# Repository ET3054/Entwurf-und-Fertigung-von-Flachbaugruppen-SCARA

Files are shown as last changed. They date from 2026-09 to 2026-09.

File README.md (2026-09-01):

# # Entwurf-und-Fertigung-von-Flachbaugruppen-SCARA
 
Dieses Repository ist Teil des Modules **IE-M13-3054** der Studierenden **Dejan Dimitrijević**, **Alexander Klose** und **Jakob Cap** an der [**Hochschule für Wirtschaft und Recht (HWR) Berlin**](https://www.hwr-berlin.de/).
 
## Grundlegende Informationen
 
Dieses GitHub-Repository befasst sich mit der Entwicklung und Fertigung eines PCBs für einen SCARA-Roboter, welcher im Rahmen des Moduls **IE-M26-6045** von den Studierenden **Jakob Cap** und **David Kowalczyk** entwickelt wurde.


  
## Repository-Struktur
 
```
├── sw/
│   ├── libraries/
|       └── XX/              	 # 
│   └── Code/              		 # 
|       └── XX/       				 # 
|       └── XX/           		 # 
├── proj/
│   └── Altimate Designer/     # PCB-Projekt
├── docs/
│   └── 3D-Design/             # 3D Dateien und technische Zeichnungen
│   └── Datenblätter/          # Datenblätter der Komponenten
│   └── Pinouts/               # Pinouts der Komponenten
└── README.md
```
## Fortschritt

 - [ ] PCB Erstellen
 - [ ] 3D Modell anpassen
 - [ ] ....

## Installation

## Nutzung

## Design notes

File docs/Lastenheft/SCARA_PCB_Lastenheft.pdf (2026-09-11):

# Lastenheft: Entwurf und Optimierung einer

# Leiterplatte zur Ansteuerung eines SCARA-Roboters

### Cap, Dimitrijevic, Klose ´

### 11. September 2026

## 1 Projektubersicht ¨

Dieses Lastenheft beschreibt die Anforderungen an eine neu zu entwickelnde Leiterplatte, die die bisherige Kombination aus ESPduino32, CNC Shield V3 und vier TMC2209-Treibermodulen im bestehenden SCARA-DJ01 ersetzt. Die Platine wird als Einzelstuck f ¨ ur den Eigenbedarf des ¨ Projekts gefertigt.

## 2 Funktionale Anforderungen

- Die Platine muss einen ESP32-Mikrocontroller als zentrale Recheneinheit enthalten.
- Die Platine muss vier Steckplatze f ¨ ur die Schrittmotortreiber-Module TMC2209-V1.3 mit ¨ der passenden Pinanordnung besitzen.
- Jeder der vier Treiberplatze soll f ¨ | ur den Betrieb im UART-Single-Wire-Modus ausgelegt ¨
sein, d.h. je Treiber eine UART-Verbindung
- Die Platine muss pro Achse eine eigene STEP- und DIR-Leitung zwischen ESP32 und Treiberplatz besitzen.
- An jedem Treiberpin fur die Motorversorgung muss ein ¨ | 100 µF-Elektrolytkondensator
gegen GND verbunden werden.
- Die Platine muss einen PWM-Ausgang zur Ansteuerung eines Servomotors fur den Grei- ¨ fer haben, inklusive Spannungsversorgung fur den Servo, im Optimalfall getrennt von ¨ der Logikspannung.
- Die Platine muss eine Statusanzeige mittels einer ansteuerbaren LED bereitstellen.
- Die Platine muss neben einer externen Bluetooth-Schnittstelle einen zusatzlichen USB- ¨ Anschluss fur die Programmierung und serielles Debugging besitzen. ¨

1

- Die Platine muss eine ausreichend stabilisierte Logikversorgung (3,3 V) fur den ESP32 ¨ und die Treiber bereitstellen.
- Die Platine muss einen Reset-Taster und einen Boot-Taster fur den ESP32 bereitstellen. ¨
- Die Platine muss eine Not-Aus-Funktion haben, die die ENABLE-Leitungen aller Treiber deaktiviert.
- Die Platine muss pro Achse mindestens ein digitales Eingangssignal fur einen Endschal- ¨ ter (Homing) verarbeiten.

## 3 Nicht-funktionale Anforderungen

- Die Platine muss mit einer Eingangsspannung von 24 V DC betrieben werden konnen. ¨
- Die maximale Außenabmessung der Platine darf 100 mm x 90 mm nicht uberschreiten. ¨
- Ein Treiberausgang muss einen Strom von mindestens 1,2 A pro Achse liefern konnen, ¨
die anderen Ausgange einen Strom von ¨ | 0,6 A.
- Die Platine muss uber mindestens vier Befestigungsbohrungen verf ¨ | ugen, deren Lochbild ¨
mit der 3D-gedruckten Montagehalterung kompatibel ist.
- Die Platine muss fur PLA-vertr ¨ | agliche Betriebstemperaturen ausgelegt sein. ¨
- Die Platine muss reproduzierbar durch Standard-Leiterplattenhersteller (z.B. JLCPCB) fertigbar sein.
- Alle Anschlussklemmen fur Motor- und Versorgungsspannung m ¨ | ussen f ¨ | ur den vorge- ¨
sehenen Maximalstrom ausgelegt sein.

2

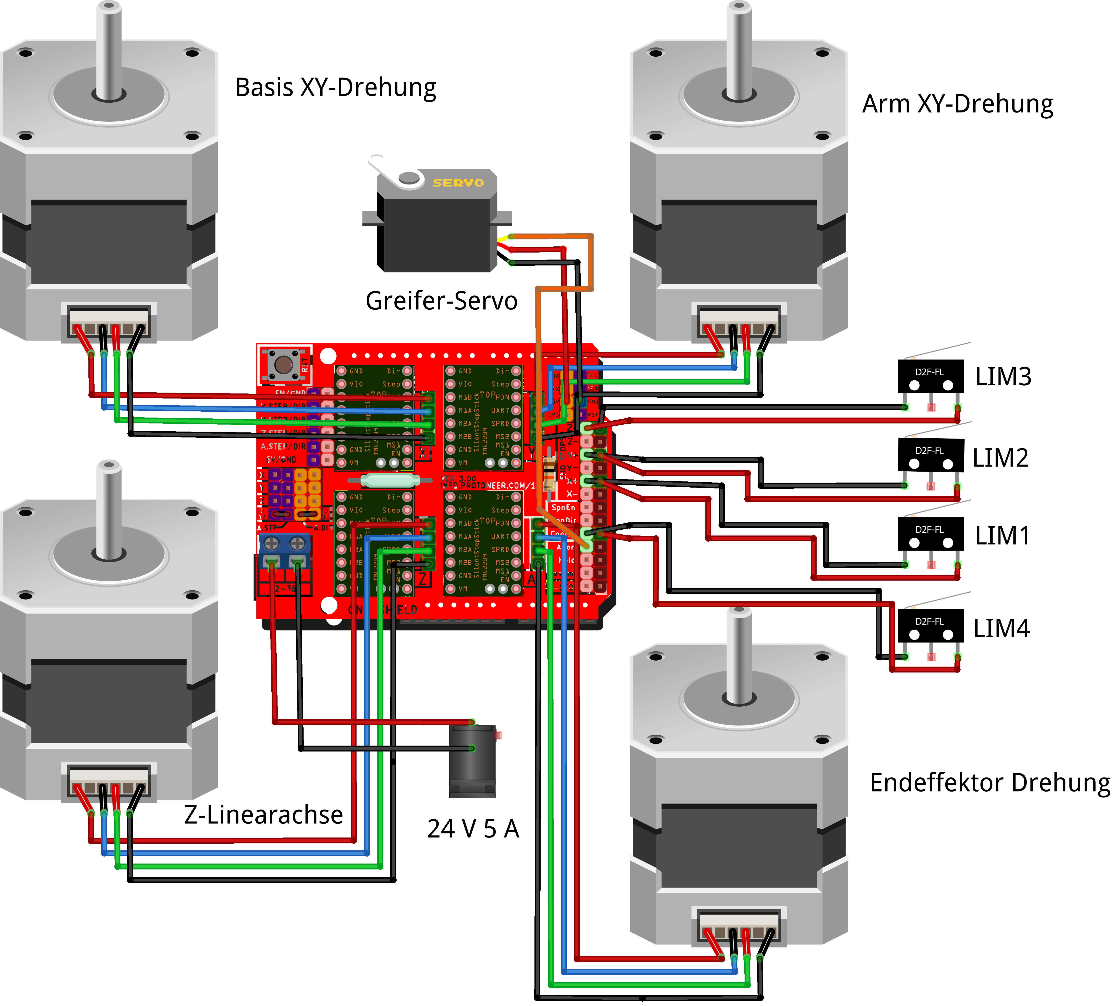
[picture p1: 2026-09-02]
docs/Schaltplan/SCARA_Symbolschaltplan_Steckplatine.png

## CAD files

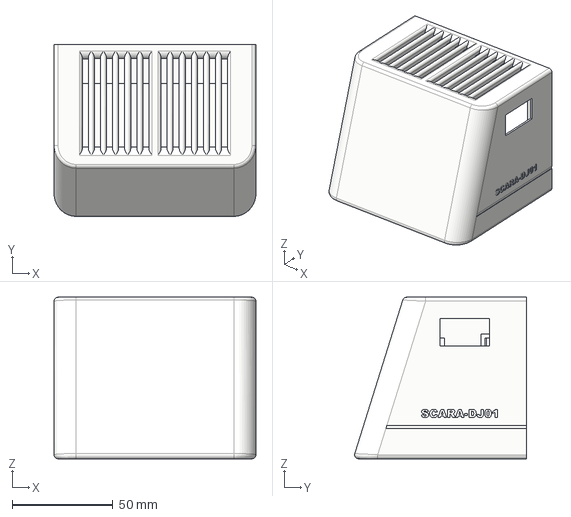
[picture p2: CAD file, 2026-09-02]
docs/3D-Design/Mikrocontrollergehäuse.step
100.0 x 85.1 x 80.0 mm

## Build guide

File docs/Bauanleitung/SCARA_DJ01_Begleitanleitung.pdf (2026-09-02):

# SCARA-Roboter

## Bauanleitung

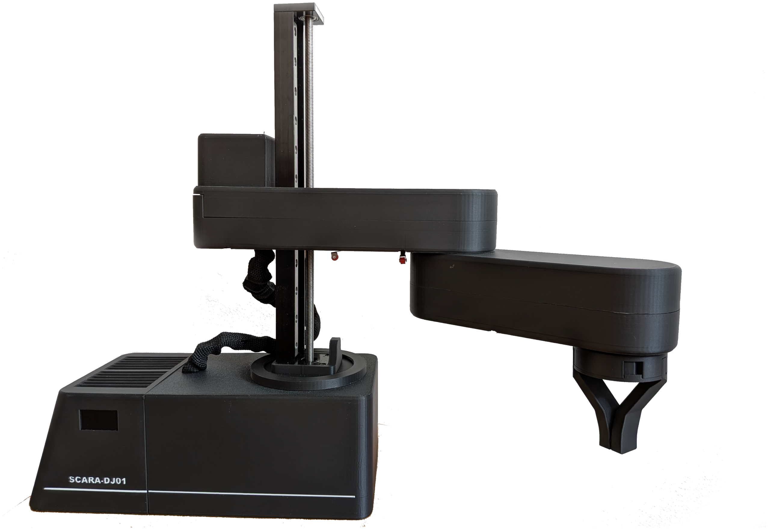
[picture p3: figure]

Datum: | 18. August 2026
Autoren: | Jakob Cap & David Kowalczyk
Fachrichtungen: | Elektrotechnik & Maschinenbau
Hochschule - Fachbereich: | HWR Berlin - Duales Studium · Technik

Einleitung

Diese Bauanleitung beschreibt den mechanischen und elektrischen Aufbau des SCARA-DJ01. Der Roboter kann einfach Handhabungsaufgaben, wie z.B. Pick-and-Place Vorgänge ausführen. Die Anleitung soll ermöglichen, den Roboter reproduzierbar aufzubauen, zu verkabeln, in Betrieb zu nehmen, zu testen und Fehler zu beheben. Dabei richtet sich die Anleitung an den Betreuer des Projekts, Studierende der industriellen Elektrotechnik und des Maschinenbaus an der HWR Berlin und Dozenten. Es werden Grundkenntnisse im sicheren Umgang mit elektrischer Spannung, mechanischer Montage, Löten und C++-Software vorausgesetzt.

Bauteilliste

Pos. | Bauteil | Bild | Anzahl | Link

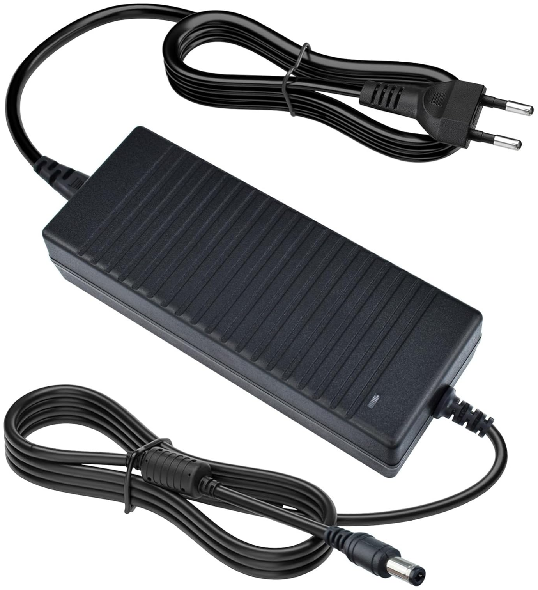
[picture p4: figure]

1 | 24 V 5 A DC-Netzteil | 1 | Amazon, (https://www.amazon.de/TOBWOLF-Netzteil-Transformatoren-Netzkabel-Sicherheitssystem-24V-5A/dp/B0BG2VMQ5Q) Aliexpress (https://de.aliexpress.com/item/4000521124523.html?curPageLogUid=9aQRAmsq0nmV)
2 | Linearmodul mit NEMA 11
Schrittmotor 6 mm Pitch
1 | Aliexpress (https://de.aliexpress.com/item/1005004275455626.html?src=google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)
3 | NEMA 11 Schrittmotor
28HS32
2 | Aliexpress, (https://de.aliexpress.com/item/4001149520746.html?curPageLogUid=TISHezQpxpRL) Reichelt (https://www.reichelt.de/de/de/shop/produkt/schrittmotor_nema_11_1_8_0_42_a_5_0_v-335321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)
4 | NEMA 17 Schrittmotor
17HS44
1 | Aliexpress, (https://de.aliexpress.com/item/1005008459399126.html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) Reichelt (https://www.reichelt.de/de/de/shop/produkt/hybridschrittmotor_nema_17_1_8_1_7_a_2_6_v-237908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)

Pos. | Bauteil | Bild | Anzahl | Link
5 | ESPduino32 | 1 | Aliexpress, (https://de.aliexpress.com/item/1005007244260396.html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) Funduino (https://funduinoshop.com/elektronische-module/wireless-iot/esp-wifi/esp32-mikrocontroller-in-uno-r3-bauform-espduino)
6 | CNC Shield V3 | 1 | Aliexpress, (https://de.aliexpress.com/item/1005006478108991.html?curPageLogUid=ZafbMuwv8aRX) Amazon (https://www.amazon.de/AZDelivery-Development-Schrittmotor-Treiber-Stepper/dp/B07CZDC9TZ)
7 | TMC2209 V1.3 Motortreiber | 4 | Aliexpress, (https://de.aliexpress.com/item/33029587820.html?curPageLogUid=3HkojVzsOqyq) Amazon (https://www.amazon.de/dp/B07WC71M4R?s=industrial&aref=RK0spETctn&sp_csd=d2lkZ2V0TmFtZT1zcF9kZXRhaWw)
8 | MG 90S Servomotor | 1 | Aliexpress, (https://de.aliexpress.com/item/1005006860780474.html?curPageLogUid=dfiFTHE6xUiC) Funduino (https://funduinoshop.com/elektronische-module/elektromotoren-und-zubehoer/elektromotoren/servomotoren/mg90s-metallgetriebe-micro-servo)
9 | Mikroendschalter mit Rollen-
kipphebel
1 | Aliexpress, (https://de.aliexpress.com/item/32949604342.html?curPageLogUid=4iSikhvUUPu3) Reichelt (https://www.reichelt.de/de/de/shop/produkt/mikroschalter_250_v_5a_1_wechsler_rollenhebel-375538)
11 | 608 Kugellager | 1 | Aliexpress, (https://de.aliexpress.com/item/1005004178119738.html?curPageLogUid=6WVQxUqaA1Xa) Amazon (https://www.amazon.de/Flewdart-Kugellager-reibungsarm-Skateboard-Abgedichtete/dp/B0FFSB9KJ4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)
12 | Nadellager mit drei Zwi-
schenlegscheiben 25x42x2
mm
1 | Aliexpress (https://de.aliexpress.com/item/1005004683503096.html)

Pos. | Bauteil | Bild | Anzahl | Link
12 | 6808 Lager 40x52x7 mm | 2 | Aliexpress, (https://de.aliexpress.com/item/32872164823.html?curPageLogUid=O13U8dG7CfZN) Amazon (https://www.amazon.de/Kugellager-40x52x7mm-Rillenkugellager-Chromstahl-Metalldichtung/dp/B0GYR3NZ1Z)
10 | GT2 Zahnriemenrad 20T-B5 | 3 | Aliexpress, (https://de.aliexpress.com/item/32995102911.html?curPageLogUid=Ju1FCh2re4OX) Amazon (https://www.amazon.de/Saipor-Zahnscheibe-Riemenscheibe-3D-Druckerteile-Zahnriemen/dp/B08X6G1WDT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)
13 | GT2 Zahnriemenspanner, mit
oder ohne Zähne, 3 mm Bohrung
4 | Aliexpress (https://de.aliexpress.com/item/1005006739452921.html?curPageLogUid=DccJLg3lUhv1) Amazon (https://www.amazon.de/Saipor-Riemenscheibe-Aluminium-Zahnriemenscheibe-Zahnriemen/dp/B092TBGXM2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)
14 | GT2-Zahnriemen
1 x 200 mm, 1 x 300 mm und 1 x 400 mm
3 | Aliexpress, (https://de.aliexpress.com/item/1005008834290222.html?curPageLogUid=SjkIp3WtWxXC) Amazon (https://www.amazon.de/Drucker-Zahnriemen-Gummiriemen-Geschlossen-3D-Drucker/dp/B0DZ6TKM8Z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)
15 | DC Power Jack | 1 | Aliexpress, (https://de.aliexpress.com/item/4001206395694.html?curPageLogUid=GMWh1VnNgcp4) Amazon (https://www.amazon.de/PATIKIL-5-5x2-5mm-Verbinder-Weiblich-Steckdose/dp/B0CLHW9CRS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)
16 | Geflochtene Kabelhülse
Innendurchmesser 10 mm
1 | Aliexpress, (https://de.aliexpress.com/item/1005007571116976.html) Amazon (https://www.amazon.de/erweiterbar-kabelschlauch-kabelstrumpf-kabelschutz-kabelmantel/dp/B071ZV6MLG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)

Pos. | Bauteil | Bild | Anzahl | Link
17 | Schrauben-Set | ∞ | Aliexpress, (https://de.aliexpress.com/i/1005007345768217.html) Amazon (https://www.amazon.de/Bnnrjia-Senkkopfschrauben-Maschinenschrauben-Flachkopfschrauben-Unterlegscheiben/dp/B0F4KJ4PNW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)

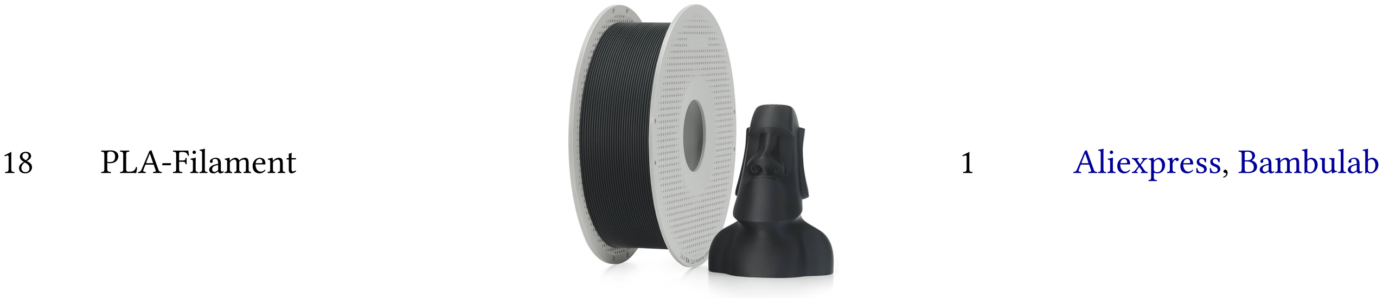
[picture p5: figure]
PLA-Filament; Aliexpress, Bambulab

19 | 0,96 Zoll OLED Display*¹
1 | Aliexpress, (https://de.aliexpress.com/item/1005007983263816.html?scm_id=1007.40050.354490.0&scm-url=1007.40050.354490.0) Amazon (https://www.reichelt.de/de/de/shop/produkt/mikroschalter_250_v_5a_1_wechsler_rollenhebel-375538)
20 | Dupont Stecker-Set*²
1 | Aliexpress, (https://de.aliexpress.com/item/1005011870146881.html?scm_id=1007.40050.354490.0&scm-url=1007.40050.354490.0) Amazon (https://www.amazon.de/Crimpzange-Dupont-Stecker-Steckverbinder-Crimpkontakten/dp/B07QX51F3B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)
21 | Schrumpfschläuche verschie-
dener Größen*²
∞ | Aliexpress, (https://de.aliexpress.com/item/1005011989139972.html?curPageLogUid=mRC6HR2zQCps) Amazon (https://www.amazon.de/sourcing-map-Schrumpfschlauch-Verh%C3%A4ltnis-Schrumpfschl%C3%A4uche/dp/B01LFJCOJ4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)
22 | Einschmelzgewinde M3 x 4
mm
4 | Aliexpress, (https://de.aliexpress.com/item/1005006472962973.html?curPageLogUid=pWqwgmMtMx5g) Amazon (https://www.amazon.de/Eins%C3%A4tze-Befestigung-metrische-Schraube-Kunststoff/dp/B09NWH5T9Kalie)

1
optional
2
hilfreich, wenn nicht vorhanden

Benötigte Werkzeuge

{ Benötigte Teile und Werkzeuge

- Schraubendreher,
- Inbusschlüssel,
- Seitenschneider/Cuttermesser,
- Multimeter,
- Lötkolben und Lötzinn,
- USB-B-Kabel,
- Laptop mit Entwicklungsumgebung und Slicing-Software,
- 3D-Drucker,
- Abisolierzange*³
,
- Crimpzange*³

Fertigung der 3D-Druck-Komponenten

1. Benötigte Ausrüstung und Material:
- Beliebiger 3D-Drucker (z.B. Bambulab P1S) mit 0,4 mm Düse
- Filament: PLA (Polylactide), Farbe optional
- Slicing-Software zum Erstellen des G-Codes für den 3D-Drucker
- Nachbearbeitung: Seitenschneider, Entgrater für das Entfernen von Stützstrukturen und Rückständen beim Drucken
2. Vorbereitung für den Druck:
- Laden der „SCARA-DJ01 3D Druck Komponenten“ in die Slicing-Software (z.B. Bambu Studio)
- Druckeinstellungen gemäß der unten abgebildeten Tabelle einstellen
- Druckvorschau überprüfen, ob Stützstrukturen, Druckzeit und Materialverbrauch stimmen
- Reinigen der Druckplatte
- Funktion „Outer brim“ im Slicer aktivieren für bessere Druckbetthaftung bei großen Bauteilen
- Druck starten

3
nicht zwingend notwendig

3. Druckeinstellungen:
Parameter | Wert
Fertigungsverfahren | FDM
Drucker | Bambulab P1S
Material | Polylactide PLA
Düsendurchmesser | 0,4 mm
Schichthöhe | 0,12 mm Fine
Fülldichte (Infill) | 15%
Stützstrukturen | tree oder normal
Druckorientierung | funktionsabhängig
4. Prüfen und Nachbearbeiten:
- Bauteile auf Maßhaltigkeit prüfen
- Probleme beim Druck? Evtl. schlechte Druckbetthaftung, wodurch es zum Verzug der Bauteile kam?
- Stützstrukturen an Bauteilen vorsichtig entfernen, insbesondere bei Kabelführungen, Passungen und Funktionsflächen achtgeben
- Bei optionaler Einstellung „Outer brim“ Rand nach der Fertigstellung zur Sicherheit entfernen
- Beim Installieren von Kugellagern in den 3D-gedruckten Bauteilen auf Sauberkeit der Passflächen achten

Montage und Inbetriebnahme des Roboters

Schritt 1

Nach Fertigstellung der 3D-gedruckten Bauteile wird das Mikrocontroller-Gehäuse zur Hand genommen und es werden die Messing-Einschmelzgewinde eingesetzt. Dafür sind vier Löcher an der Rückwand des Mikrocontroller-Gehäuses vorgesehen. Mithilfe z.B. eines heißen Lötkolbens werden die M3 x 4 mm-Gewinde vorsichtig in den Kunststoff eingeschmolzen.

ò

Falls das optionale OLED-Display verbaut werden soll, ist es ratsam, kurz zum sechsten Schritt in dieser Anleitung zu springen und anschließend mit Schritt 2 fortzufahren.

Schritt 2

Im zweiten Schritt wird der ESPduino32 an die entsprechenden Löcher gesetzt und mit vier M3 x 6-Schrauben gesichert. Die Schrauben sollten leicht handfest angezogen werden. Es ist darauf zu achten, dass die Aussparungen am Mikrocontrollergehäuse und die Anschlüsse des ESPduino32 korrekt ausgerichtet sind.

Da der ESP in dieser Position am leichtesten erreichbar ist und beim späteren Hochladen des Codes Probleme auftreten könnten, wird die Software bereits jetzt auf den Mikrocontroller übertragen. Damit das Programm SCARA_DJ01_control_sw auf den ESPduino übertragen werden kann, muss der Mikrocontroller in den Bootloader-Modus versetzt werden. Beim Einschalten prüft der ESP den Zustand bestimmter Pins. Ist der Pin GPIO0 mit GND verbunden, startet er nicht das bereits gespeicherte Programm, sondern wechselt in den Bootloader-Modus und wartet auf das Aufspielen einer Software. Bei Verwendung eines geeigneten USB-Kabels und den entsprechenden Einstellungen in der Arduino IDE sorgt eine Schaltung auf der Leiterplatte dafür, dass der Bootloader-Modus automatisch aktiviert werden kann. Sollte dies nicht funktionieren und beim Flashen wird eine Fehlermeldung ausgegeben, muss der Pin GPIO0 manuell mit GND verbunden werden. Hierzu wird der Pin GPIO0 mit einem GND-Pin über ein Jumperkabel verbunden. Dann kann der Upload in der Arduino IDE gestartet werden. Nach erfolgreichem Flashen wird die Verbindung entfernt und die RESET-Taste kurz betätigt, sodass der Mikrocontroller neu startet und das aufgespielte Programm ausführt.

Optimale Einstellungen der Arduino IDE für das Flashen auf den ESPDuino

Einstellung | Wert
Board | ESP32 Dev Module
Flash Frequency | 40 MHz
Flash Mode | DIO

Erase All Flash Before Sketch Upload Enabled

Upload Speed | 115200

Schritt 3

Bevor das CNC Shield inklusive der Motortreiber auf dem ESPduino32 aufgesetzt werden, müssen die Motortreiber korrekt eingestellt werden. Die vier Schrittmotoren des SCARA-Roboters werden über je einen TMC2209 V1.3 Schrittmotortreiber angesteuert. Jeder Schrittmotor besitzt einen maximal zulässigen Phasenstrom IN, der dem Datenblatt zu entnehmen ist. Um eine thermische Überlastung des Motors zu vermeiden, muss die Referenzspannung Uref, die den Phasenstrom begrenzt, für jeden Treiber korrekt eingestellt werden.

Für die TMC2209 V1.3 Module mit einem Shunt-Widerstand von RSENSE = 0,11 Ω gilt näherungsweise folgende Gleichung:

Uref =

√
2 · IRMS

Dabei ist IRMS der gewünschte Effektivstrom des Motors, der für diesen Entwurf testweise ermittelt wurde. Für den NEMA 17-Motor mit einem angestrebten Phasenstrom von 1,2 A in diesem Entwurf
ergibt sich Uref zu | 1,7 V | .

Für die drei NEMA 11-Motoren mit einem angestrebten Phasenstrom von 0,6 A ergibt sich Uref zu 0,85 V .

ò

Da verschiedene Hersteller der TMC2209 V1.3 Module unterschiedliche Shunt-Widerstände verbauen können, ist die im Datenblatt des jeweiligen Moduls angegebene Formel stets zu überprüfen. Die in diesem Kapitel verwendeten Werte gelten ausschließlich für die im Projekt eingesetzten Treibermodule.

Uref wird über ein Potentiometer auf dem Modul eingestellt. Um die Referenzspannung mit einem Multimeter zwischen Schleifer des Potentiometers und GND-Pin zu messen, muss der Treiber mit Motorspannung versorgt sein. Dazu bietet es sich an, die Motortreiber direkt auf dem CNC Shield aufgesteckt einzustellen. Das CNC Shield muss mit Motorspannung versorgt werden, z.B. über das 24 V DC-Netzteil. Da im vierten Schritt auch der DC Power Jack benötigt wird kann dieser im Optimalfall gleich dafür verwendet werden. Der positive und negative Anschluss sollten dafür mit einem kurzen Kabel verlötet und abisoliert werden. Die offenen Enden sind den richtigen Schraubklemmen des CNC Shields zu befestigen (Unbedingt auf richtige Polarität achten!).

Folgende wichtige Hinweise bevor mit der Einstellung des Phasenstroms begonnen wird:

- Bei der Montage der Treiber auf dem CNC Shield ist unbedingt die physische Orientierung zu beachten. Andernfalls können die Treiber dadurch beschädigt werden, dass die Motorspannung auf den Logikpins anliegt.
- Der TMC2209 V1.3 ist ursprünglich nicht für die Montage auf dem CNC Shield V3 ausgelegt. Wichtig zu wissen ist, dass folglich nicht alle Pin-Belegungen beider Bauteile übereinstimmen. Trotzdem ist die Nutzung der Module möglich, es gilt nur zu beachten, dass die oberen UART-Pins (DIAG,INDEX, falls vorhanden) Kontakt mit den Kondensatoranschlüssen auf dem CNC Shield haben könnten. Das sollte vermieden werden, indem die Pins vorsichtig nach außen gebogen oder heraus gelötet werden.
- Es ist auch zu bedenken, dass die Schrittmotor-Phasenkabel nicht unter Spannung anoder abgesteckt werden sollten. Das kann zu induktiven Spannungsspitzen führen, die die Treiber ebenso beschädigen können.

Vorgehensweise zur Einstellung des Phasenstroms

Für die Einstellung werden ein Multimeter, ein Kreuz-Schlitz-Schraubendreher und eine Spannungsversorgung benötigt. Der Schrittmotor kann während der Einstellung abgesteckt bleiben. Die Einstellung erfolgt für jeden der vier TMC2209-Treiber identisch.

1. Treibermodul auf CNC Shield stecken
2. Spannungsversorgung einschalten
3. Multimeter auf Gleichspannungsmessung einstellen
4. Schwarze Messspitze mit einem GND-Pin des Treibers verbinden
5. Rote Messspitze auf das Potentiometer halten
6. Aktuelle Referenzspannung ablesen
7. Potentiometer vorsichtig drehen:

- im Uhrzeigersinn: erhöht die Referenzspannung und den Phasenstrom
- gegen den Uhrzeigersinn: verringert die Referenzspannung und den Phasenstrom
8. Einstellwert mit Sollwert vergleichen
9. Vorgang für alle restlichen Treiber wiederholen

Sind alle Treiber eingestellt können sie auf die vier Slots des CNC Shields verteilt werden. Der Treiber für den NEMA 17-Schrittmotor mit einer eingestellten Referenzspannung von 1, 7 V ist für den X-Slot vorgesehen. Die restlichen Treiber können auf die Slots Y, Z und A verteilt werden. Zur Aktivierung des A-Slots müssen Jumper auf die Male-Pin-Header D12/A.STEP und D13/A.DIR gesetzt werden (direkt über den Schraubklemmen des Shields). Schließlich kann das Shield auf den ESPduino32 aufgesteckt werden.

ò

Das CNC Shield V3 wurde ursprünglich für einen Arduino UNO R3 entwickelt. Der ESPduino32 ist ein ESP32-Mikrocontroller mit einer ähnlichen Bauform und Pin-Anordnung wie der UNO R3. Es ist festzustellen, dass manche Komponenten auf den Modulen z.B. durch Montagetoleranzen verschoben angeordnet sind. So kommt es bei manchen Modellen vor, dass der USB-B-Anschluss ein Stück weiter hinten auf dem Modul versetzt ist. Dadurch kann das Shield nicht korrekt aufgesetzt werden, da die Pins mit der Unterseite auf dem USB-Port aufliegen. Das führt wiederum dazu, dass die betroffenen Schritt- und Richtungs-Pins auf dem Erd-Potential der Schnittstelle liegen. Dadurch kam es in diesem Entwurf oft zu Ausfällen einzelner Motoren. Hier kann mit einem Seitenschneider und ein wenig Isolierband Abhilfe geschaffen werden. Wenn die betroffenen Pin-Enden auf der Unterseite vorsichtig abgeschnitten und mit Isolierband abgeklebt werden, können zukünftige Ausfälle verhindert werden.

Schritt 4

Im vierten Schritt wird der DC Power Jack mit den bereits angelöteten Kabeln in die dafür vorgesehene Aussparung im Mikrocontrollergehäuse gesteckt. Die offenen Enden werden (falls noch nicht geschehen) an den Schraubklemmen des CNC Shields befestigt. Da der Bauraum begrenzt ist, sollte die benötigte Kabellänge vom DC Power Jack zum Shield durch Ausprobieren ermittelt werden.

Schritt 5

Nun kann der 3D-gedruckte Haltebügel für den DC-Jack montiert werden. Die M2 x 6-Schrauben werden durch die vorgesehenen Löcher im Haltebügel gesteckt und dieser anschließend an die vorgesehenen Löcher im Mikrocontrollergehäuse geschraubt.

Schritt 6

Das Mikrocontrollergehäuse ist nun fertig zusammengebaut.

Falls das optionale OLED-Display montiert werden soll, ist ein wenig handwerkliches Geschick notwendig. Das Display wird in die dafür vorgesehene Passung am Gehäuse eingesetzt und mit einem langen schmalen Schraubenzieher durch die Löcher der DC-Anschlüsse im Gehäuse auf der anderen Seite festgeschraubt. Die beschrifteten I²C-Pins des Shields stimmen nicht mit den Pins auf dem ESPduino32 überein, da es ursprünglich für den UNO R3 konzipiert wurde. Die Montage ist jedoch möglich, da das CNC Shield die Pins auf dem ESPduino nicht nutzt und sie daher quasi frei sind. Man kann zwei Arduino Jumperkabel so umbiegen, dass sie im 90°-Winkel aus den freien Female-Header-Pin (SCL, SDA) des ESPduinos unter dem CNC Shield entlang geführt werden. Vcc des OLED-Displays kann mit 3, 3 V auf dem CNC Shield verkabelt werden und GND mit einem jeweiligen GND-Pin.

Schritt 7

Im siebten Schritt wird der untere Teil des großen Basis-Gehäuses verwendet. Die Welle des NEMA 17-Schrittmotors wird mit einem GT2 Antriebsrad mit 20 Zähnen bestückt und anschließend werden die Madenschrauben des Antriebsrades so angezogen, dass die Oberkante des Antriebsrads mit der Oberkante der Motorwelle abschließt. Nun kann der NEMA 17 in die dafür vorgesehene Passung im Gehäuse eingesetzt, aber noch nicht verschraubt werden. Die Kabelanschlüsse des Motors zeigen dabei in Richtung Mikrocontrollergehäuse.

Schritt 8

Das Kugellager 608 wird in die kreisrunde Passung am Boden des Gehäuses eingesetzt. Hierbei ist auf die Presspassung zu achten.

Der Lagerbolzen wird mit der kurzen Seite nach unten vorsichtig eingedrückt. Im Anschluss daran wird der NEMA 17-Motor kurz in der Passung angehoben, sodass der 200 mm GT2 Riemen um das Antriebsrad geführt werden kann. Schließlich kann auch der Motor von der Unterseite des Gehäuses mit vier M3 x 16-Schrauben befestigt werden

Schritt 9

Das GT2 Zahnriemenrad mit 60 Zähnen und einer 8 mm Bohrung wird auf den Lagerbolzen gesetzt. Dabei sollte der Riemen bereits um das Antriebs- und Abtriebsrad gelegt sein. Einer der Endlagentaster wird in die Gehäusepassung eingesetzt (Orientierung beachten). Die Kabelanschlüsse des Endlagentasters sind nach Möglichkeit zu Löten. Alle Endlagentaster sind in diesem Entwurf als Normally Closed konfiguriert. Das bedeutet der mittlere Anschluss der Taster bleibt unbelegt und nur die beiden äußeren werden verlötet. Hierfür sollten zwei ca. 20 cm lange Kabel verwendet werden, die zum Schluss des Zusammenbaus auf die richtige Länge gekürzt werden. Die gelöteten Kabelanschlüsse am Taster sind nach Möglichkeit mit etwas Isolierband oder Schrumpfschlauch zu isolieren. Die entgegengesetzten Enden der beiden Kabel können nach dem Kürzen z.B. in einen zweipoligen Dupont-Female-Connector geführt werden, sodass zum Schluss eine einfache Steckbarkeit auf dem CNC Shield gewährleistet wird.

Schritt 10

Im zehnten Schritt wird das Verbindungselement auf das Abtriebsrad gesetzt und anschließend mit einer Madenschraube gesichert. Der Endlagentaster wird mit zwei M2, 5 x 10-Schrauben in der

Passung befestigt. Da diese Schrauben direkt in das PLA gedreht werden, sollten sie nur leicht festgezogen werden. Gleiches gilt für alle folgenden Schraubverbindungen im PLA.

Schritt 11

Um den Riemen zu spannen, wird ein Riemenspanner eingesetzt. Hierzu wird die M2 x 20-Schraube von der Unterseite des Gehäuses ein kleines Stück in das Gehäuse eingeschraubt und schließlich werden zwei M2-Muttern aufgeschraubt. Danach wird der Riemenspanner aufgesetzt, sodass er den Riemen nach innen drückt. Die Schraube wird nun weiter durchgeschraubt und oben mit einer weiteren M2-Mutter gekontert und dann in das Loch an der Unterseite des NEMA 17-Halters geschraubt. Die Muttern sollten so festgeschraubt werden, dass sich der Riemenspanner leichtgängig drehen lässt.

Schritt 12

Mit dem zwölften Schritt ist die Montage des unteren Basis-Gehäuses abgeschlossen.

Schritt 13

Nun wird das Linearmodul für die Montage vorbereitet. Dazu ist ein Inbusschlüssel der Größe 2 mm notwendig. Mit diesem werden zunächst die vier Schrauben gelöst, die den Schrittmotor sichern. Anschließend wird der Schrittmotor inklusive Kugelumlaufspindel vorsichtig ein Stück aus der Schiene herausgezogen. Daraufhin wird der Motor durch das Trägerbauteil geführt und die Schiene in die Passung eingesetzt. Danach kann der Motor wieder mit der Schiene verschraubt werden.

Bei dem Aufsetzen des Kugellagers auf das Trägerbauteil ist unbedingt auf die Presspassung zu achten. Falls der Vorgang schwergängig ist, kann das Kugellager auch erst in die obere Gehäusehälfte eingepresst werden. Auf keinen Fall sollte sich auf der Oberseite des Linearmoduls abgestützt werden. Dadurch kann sich das Material verformen und die Leichtgängigkeit des Schiebers wird beeinflusst. Sollte der Schieber sich trotzdem immer noch sehr schwergängig von Hand bewegen lassen, besteht die Möglichkeit, die zwei Inbusschrauben an der Oberseite des Schiebers zu lösen und das Spiel zwischen Schieber und Schiene zu korrigieren.

Schließlich wird der Sicherungsriegel von der Oberseite über das Linearmodul geführt, sodass er mit den acht Löchern nach unten zeigend auf dem Trägerbauteil aufliegt.

Schritt 14

In diesem Schritt wird das Linearmodul durch das Loch in der oberen Basis-Gehäusehälfte geführt und das Kugellager vorsichtig in die Passung eingepresst (ggf. Kugellager zuerst einsetzen, siehe Schritt zuvor). Von der Unterseite ist der Sicherheitsriegel mit acht M3 x 8 Schrauben zu sichern.

Schritt 15

Für die Montage des ersten Roboterarms wird zuerst das Kugellager in die dafür vorgesehen Passung eingepresst. Das GT2 Abtriebsrad mit der großen Bohrung wird in den Kugellagerinnenring eingepresst. Außerdem werden zwei Endschalter für die Z-Achse und die XY-Drehung des zweiten Arms in die Passung nach der Verkabelung eingesetzt. Die Verkabelung sollte wie in Schritt 9 ausgeführt werden. Auch auf passende Kabellängen sollte geachtet werden, die dann durch die Kabelführungen in der Seitenwand des Gehäuses nach unten durch das Loch geführt werden. Da die Schalter möglicherweise in ihrer Passung verrutschen könnten, empfiehlt es sich sie durch die Löcher mit zusätzlichen Schrauben zu sichern und diese auf der anderen Seite mit einer Mutter zu kontern.

Schritt 16

Im Folgenden kann der vorbereitete Arm über das Linearmodul geführt werden und am Schieber mit vier M3 x 10 Schrauben montiert werden.

Schritt 17

Im Schritt 17 wird der obere Teil des ersten Roboterarms vorbereitet. Ein GT2 Antriebsrad mit 20 Zähnen wird auf der Motorwelle des NEMA 11-Schrittmotors befestigt. Dann wird der Motor in die Passung eingesetzt und mit vier M2, 5 x 12 Schrauben fixiert. Die vier Motorphasen-Kabel werden durch das Loch daneben nach unten geführt.

Schritt 18

Das Gehäuse für den Motor wird ebenso mit vier M2, 5 x 12 Schrauben von der Unterseite gesichert. Die Riemenspanner werden in den Aussparungen verbaut. Dafür werden zwei M2 x 20 Schrauben von oben durch das Loch gesteckt, anschließend mit einer Mutter gekontert und der jeweilige Riemenspanner wird aufgesteckt, der wiederum mit einer Mutter gekontert wird. Der 400 mm Riemen kann schon mal provisorisch außen um das Antriebsrad und die beiden Riemenspanner herumgelegt werden.

Schritt 19

Bevor die beiden Gehäuse des ersten Arms miteinander verbunden werden können, wird die obere Hälfte des zweiten Roboterarms mit der unteren Hälfte des ersten verschraubt. Dafür wird das obere Gehäuse von Arm 2 in die Passung am Arm 1 eingesetzt, sodass die Löcher auf der kreisförmigen Fläche mit den Löchern im Abtriebsrad des ersten Arms übereinstimmen. Zwei Schrauben M3 x 16 fixieren diese Verbindung und der zweite Arm sollte sich nun leichtgängig im Kugellager drehen lassen.

Schritt 20

In diesem Schritt wird der untere Teil des zweiten Arms inklusive der gesamten Verkabelung vorbereitet. Der Endschalter für die Greiferrotation wird wie in Schritt 9 vorbereitet und die Kabel werden durch die große Bohrung im Zahnriemenrad des ersten Arms, durch die Kabelführungen und durch das Loch im Boden des Gehäuses gezogen. Das letzte GT2-Antriebsrad mit 20 Zähnen wird auf der Motorwelle des NEMA 11 montiert, sodass das Antriebsrad so nah wie möglich am Motor befestigt wird, ohne zu schleifen. Bevor der Motor mit vier M2, 5 x 6 Schrauben gesichert wird, sollte der Riemen um das Antriebsrad gelegt werden. Der Motor wird so montiert, dass die Phasenkabel bei nach vorne ausgestreckten Armen in Richtung des ersten Roboterarms zeigen und die Kabel werden durch die erweiterte Bohrung im GT2-Zahnriemenrad geführt. Die Verlegung der Kabel durch die Kabelführungen erfolgt wie gehabt, sodass die Kabel durch das Loch an der Unterseite des ersten Arms durchkommen. Der MG90S Mikro Servomotor wird in die Passung des letzten Zahnriemenrads eingesetzt und anschließend mit zwei Schrauben fixiert. Das axiale Nadellager wird mit jeweils einer Zwischenlegscheibe oben und einer unten in die Passung eingesetzt und anschließend wird das GT2-Zahnriemenrad eingesetzt und dabei der Riemen herumgelegt.

Schritt 21

Der Endschalter wird mit zwei M2, 5 x 10 Schrauben montiert und die Vorbereitung des zweiten Arms ist so gut wie abgeschlossen.

Schritt 22

An der Unterseite des zweiten Arms wird nach einer Zwischenlegscheibe die Greiferarm-Führung mit zwei M3 x 12 Schrauben am GT2-Zahnriemenrad montiert.

Schritt 23

Bei der Montage des erweiterten Servo-Zahnrads ist Vorsicht geboten. Es hat eine innere Verzahnung, die auf das Zahnrad des Servos greifen soll. Da das 3D-Druck-Material schnell beschädigt werden kann, wird es empfohlen den Servomotor nochmals auszubauen und das Zahnrad probeweise auf der Welle des Servos zu befestigen. Anschließend kann der Servo wieder verbaut werden und das Greiferzahnrad kann durch das Loch auf die Welle des Servos gedrückt und durch eine M2, 5 x 6 Schraube innen fixiert werden.

Schritt 24

Im Schritt 24 können die beiden Greiferarme bereits probeweise verbaut werden, spätestens bei der ersten Initialisierung müssen sie jedoch wieder demontiert werden. Das hat den Grund, dass sich der Servo seine Positionsreferenz über eine Referenzspannung holt, die an einem Potentiometer gemessen wird, das durch das Servo-Getriebe betätigt wird. Ist der Greifer nun montiert und die Greifarme sind bspw. geschlossen (theoretisch 0°) und das Motorpotentiometer steht aber praktisch auf 100°, entspricht das nicht der angestrebten Position. Wird der Roboter angeschaltet und der Servo wird auf 0° gesetzt, aber das Potentiometer steht noch bei 100° während die Arme geschlossen, wird der Servo versuchen, die geschlossenen Arme zu schließen und dabei potenziell kaputtgehen. Deswegen sollten die Greiferarme für die allererste Initialisierung des Servos demontiert werden. Anschließend sollte der Servo in der SCARA Control App auf 0° gefahren werden und dann können die Arme in der geschlossenen Position montiert werden.

Schritt 25

Mit der Sicherungsplatte des Greifers werden die Greiferarme vor Herausfallen gesichert. Die Verschraubung erfolgt durch zwei M3 x 8 Schrauben.

Schritt 26

Schließlich werden die beiden Gehäusehälfen des zweiten Arms mit drei M3 x 16 Schrauben verbunden.

Es ist insbesondere auf die Kabelführung des Schrittmotors zu achten, sodass keine Kabel gequetscht werden. Außerdem sollte der Clip der unteren Gehäusehälfte beim Zusammenbau vorsichtig in die Vertiefung der oberen Hälfte einrasten

Schritt 27

Die beiden Gehäusehälften des ersten Arms werden dadurch verbunden, dass der Linearmodul-Schieber bis an die obere Grenze der Schiene geschoben wird. Der Zahnriemen, der um die Riemenspanner und das Zahnriemenrad an der oberen Gehäusehälfte gelegt ist, wird jetzt beim Zusammenbau auch um das Abtriebsrad gelegt. Dann werden die Teile vorsichtig zusammengedrückt und anschließend mit vier M3 x 16 Schrauben von der Unterseite fixiert.

Schritt 28

Im vorletzten Schritt geht es an die Verkabelung der Endlagentaster, des Servomotors und der Schrittmotoren auf dem CNC Shield. Dazu gibt es folgenden Schaltplan, der aufgrund eingeschränkter Lesbarkeit erläutert wird:


ò

Es wird empfohlen, die Kabel zu beschriften

Alle Kabel, die Komponenten in den beiden Roboterarmen betreffen, sollten nun aus dem Loch an der hinteren Unterseite des ersten Arms herauskommen. Kabel, die zu kurz sind, müssen verlängert werden. Dies betrifft wahrscheinlich die Motorphasenkabel der NEMA 11-Schrittmotoren und die Kabel des Servomotors. Die Verbindungen sollten im besten Fall gelötet und anschließend mit einem Schrumpfschlauch isoliert werden. Steckverbindungen sind theoretisch möglich, jedoch wird dadurch der Gesamtquerschnitt des Kabelbaums vergrößert, was zu Problemen bei der Montage der Kabelhülse führen kann. Sind alle Kabel verlängert, kann die Kabelhülse über den gesamten Kabelbaum geführt werden und anschließend durch das Loch im Basisgehäuse geschoben werden. Hier können die Kabel jetzt auf die richtige Länge gekürzt werden und nach Möglichkeit in Dupont-Stecker gecrimpt werden. Bei den Schrittmotoren gilt einzig zu beachten, dass die beiden Kabel einer Phase, z.B. rot und blau im Dupont-Stecker direkt nebeneinander angeordnet sein müssen. Begonnen wird mit dem ersten Endschalter im Basisgehäuse. Dieser wird mit beiden Pins auf der Position X+ auf dem CNC Shield platziert. Der Endschalter für die Z-Achse im ersten Arm wird auf Z+ gesteckt und der für die XY-Drehung des zweiten Arms auf die Position Y+. Schließlich wird der Endschalter zur Kalibrierung der Greiferrotation auf CoolEn montiert. Der Servomotor sitzt auf 5 V, GND und das PWM-Signal auf dem Pin Abort des CNC Shields. Die Zuordnung der Kabelfarben ist entsprechend dem Datenblatt zu entnehmen. Der NEMA 17-Schrittmotor wird auf die Pin-Header von Slot X gesteckt, das Linearmodul auf Z, der NEMA 11 auf Arm 1 auf Y und der NEMA 11 für die Greiferrotation auf A.

Sind alle Komponenten verdrahtet, folgt die Montage des Mikrocontrollergehäuses an der Basis. Dazu werden die Kabel vorsichtig zusammengerollt und das Mikrocontrollergehäuse wird in die Verhakungspunkte an der Oberseite des Basisgehäuses eingehangen. Anschließend wird es leicht nach unten gedrückt und geschlossen.

Schritt 29

Mit Schritt 29 ist die Montage abgeschlossen und es folgt die Inbetriebnahme. Dazu ist eine Logikversorgung für den Mikrocontroller und das 24 V DC-Netzteil notwendig.

Es sollte sich entschieden werden, ob der Roboter über serielle Schnittstelle in der Arduino IDE oder über die entwickelte SCARA Control App mit Bluetooth in Betrieb genommen werden soll. Für die App gibt es die mitgelieferte SCARA_control_androidapp apk-Datei. Diese kann nur für das Betriebssystem Android heruntergeladen werden. Die App ist größtenteils selbsterklärend aufgebaut, sodass auf die konkreten Funktionen nicht weiter eingegangen werden soll.

Wird der Mikrocontroller zuerst mit Spannung versorgt (z.B. über die USB-Schnittstelle) wird automatisch auch das Bluetooth unter dem Namen SCARA_DJ01 gestartet. In der App wird sich dann mit dieser Adresse verbunden, sodass anschließend string-Befehle an den Mikrocontroller gesendet werden können. In der folgenden Tabelle sind alle string-Befehle und die jeweilige Funktion aufgelistet, die auch per serieller Schnittstelle an den Mikrocontroller gesendet werden können:

Übersicht der verfügbaren Befehle

Befehl | Funktion
stop | Motoren stoppen sofort
enable | Motoren werden nach stop wieder aktiviert
h | Homing aller vier Achsen
fk | Vorwärtskinematik berechnen und ausgeben
ik | Invers-Kinematik-Fahrt zur Zielposition
gp | Greifer-Winkel setzen (0–180◦ )
sp | Geschwindigkeit setzen (Steps/s)
ac | Beschleunigung setzen (Steps/s² )
a1-a4 | Ansteuerung der Einzelachsen (◦ /mm)
sik | Sequenzpunkt speichern
sikg | Sequenzpunkt und Greifer-Winkel speichern
seq | Gespeicherte Sequenz ausgeben
run | Sequenz abfahren
loop | Sequenz wiederholt abfahren
ls | Laufende Schleife beenden
clear | Sequenzspeicher löschen
del | Letzten Sequenzpunkt löschen
demo | Eingebaute Demo-Sequenz ausführen
demoloop | Demo-Sequenz wiederholt ausführen

Einige wichtige Hinweise noch:

- Die Greiferarme sollten für die allererste Initialisierung demontiert werden. Anschließend wird der Servo in der SCARA Control App auf 0° gefahren werden und dann können die Arme in der geschlossenen Position montiert werden. Für Erläuterung siehe Schritt 24.
- Vor dem Homing sollten die beiden Arme möglichst nicht nach hinten ausgerichtet sein, um so konstruktive Zusammenstöße der Arme beim Verfahren des Linearmoduls zu verhindern. Das Homing wird durch den Command h im seriellen Monitor bzw. durch Betätigung des Homing-Buttons in der SCARA-Control App ausgelöst. Hier gibt es einiges zu beachten. Zum einen ist unbedingt auf die Verfahrrichtung der Achsen zu achten, denn eine Bewegung in die falsche Richtung führt unweigerlich zu einer konstruktiven Beschädigung der Bauteile bzw. Überlastung des Motors. Fährt eine Achse, z.B. die Z-Achse nun in die falsche Richtung (z.B. nach oben statt nach unten), ist entweder sofort die Stromversorgung zu trennen oder die Not-Aus Taste in der SCARA-App zu betätigen. Anschließend sollte der Motorphasenkabel-Stecker um 180° gedreht werden und das Homing kann erneut gestartet werden. Wenn sich alle Achsen in die richtige Richtung bewegen, ist das Homing korrekt konfiguriert. Der nächste Schritt ist die Ausrichtung der Arme. Da sich die Endschalter-Positionen und Auslösezeitpunkte von Modell zu Modell geringfügig unterscheiden, ist es meist notwendig nach dem Zusammenbau die Schrittoffsets in der Software manuell anzupassen, damit die Arme in einer perfekten Nullposition (beide Arme nach vorne getreckt stehen). Das betrifft vor allem die Offsets von Motor1 (OFF1) und Motor3 (OFF3). Hier sollte durch Probieren ermittelt werden, wann die Arme perfekt nach vorne ausgerichtet sind. Als Referenz: 13,333 Schritte in die eine oder andere Richtung entsprechen ± 1°. Ist das Homing erfolgreich konfiguriert, ist bei anschließenden Inbetriebnahmen keine Anpassung der Offsets notwendig. Alle Achsen haben beim Homing eine physische Begrenzung: die Z-Achse fährt nach unten, bis der Endschalter auslöst, die X-Achse im Uhrzeigersinn und die Y-Achse gegen den Uhrzeigersinn und die Greiferrotation ebenso gegen den Uhrzeigersinn. Beim Greifer ist darauf zu achten, dass er möglichst schon vor dem Homing ungefähr parallel steht, da der Greifer gegen den Uhrzeigersinn kalibriert. Wenn er dann schon über dem Endschalter hinaus steht, kann es passieren, dass er sich um praktisch 360° dreht, bevor der Endschalter auslöst und sich dadurch das Servo-Kabel verdreht.
- Nach der Inbetriebnahme sollte die Temperatur von Motoren und Treibern kontrolliert werden. Die Gehäusetemperatur der Treiber darf zwar warm werden, jedoch ist ein Erreichen der thermischen Abschaltung zu verhindern

Fehlersuchtabelle

Fehlerbild | Mögliche Ursache | Maßnahme
Roboter bewegt sich nicht | Keine Versorgungsspannung, Lo- gikspannung | Netzteil und Logikversorgung prüfen, RST-Taste auf ESP betä- tigen
Motor dreht nicht | Motorphasenkabel stecken nicht richtig, STEP/DIR Pins deakti- viert | Prüfen der Steckverbindungen am CNC Shield

Motor zittert/vibriert und bewegt sich nicht unter
Last

Motorphasenkabelbruch, Steckverbindungen CNC Shield sitzen nicht richtig

Prüfen der Steckverbindungen am CNC Shield, auf Kabelbruch prüfen

Linearmodul sehr schwergängig

Schieber und Kugelumlaufspindel verspannt

Ausrichtung des Schiebers mit den zwei Imbusschrauben an der Oberseite justieren

Arm-Rotation sehr
schwergängig

Verspannung oder Verzug der 3D-Druck-Komponenten

Neu Drucken, Material bearbeiten bzw. Verspannung lösen

Homing: Motor verfährt
in die falsche Richtung
Phase A und B vertauscht | Steckverbindung am CNC Shield um 180 drehen

Homing: Endschalter löst
gar nicht aus
Kabelbruch, Endschalter sitzt nicht richtig auf CNC Shield | Auf Kabelbruch und Steckverbin- dung am CNC Shield prüfen

Homing: Nicht alle Achsen werden gehomed bzw.
bewegen sich beim Homing
Endschalter ist gedrückt oder Ka- belbruch und löst somit direkt aus, sodass die jeweilige Ach- se beim Homing übersprungen wird | Auf Kabelbruch, Steckverbin- dung am CNC Shield, korrek- te Verlötung (NC) und mechani- sche Behinderung prüfen.
Homing: | Roboterarme
sind nach Homing nicht
perfekt in der Nullposition (beide Arme nach
vorne gestreckt)

Homing-Offsets stimmen nicht Schrittoffsets in der Software anpassen (zur Orientierung: 10° Drehung entsprechen 133 Schritten)

Roboter macht, was er
will
Stackoverflow | Software anpassen

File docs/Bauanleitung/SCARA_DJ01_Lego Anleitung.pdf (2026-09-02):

# SCARA DJ01

# Anleitung

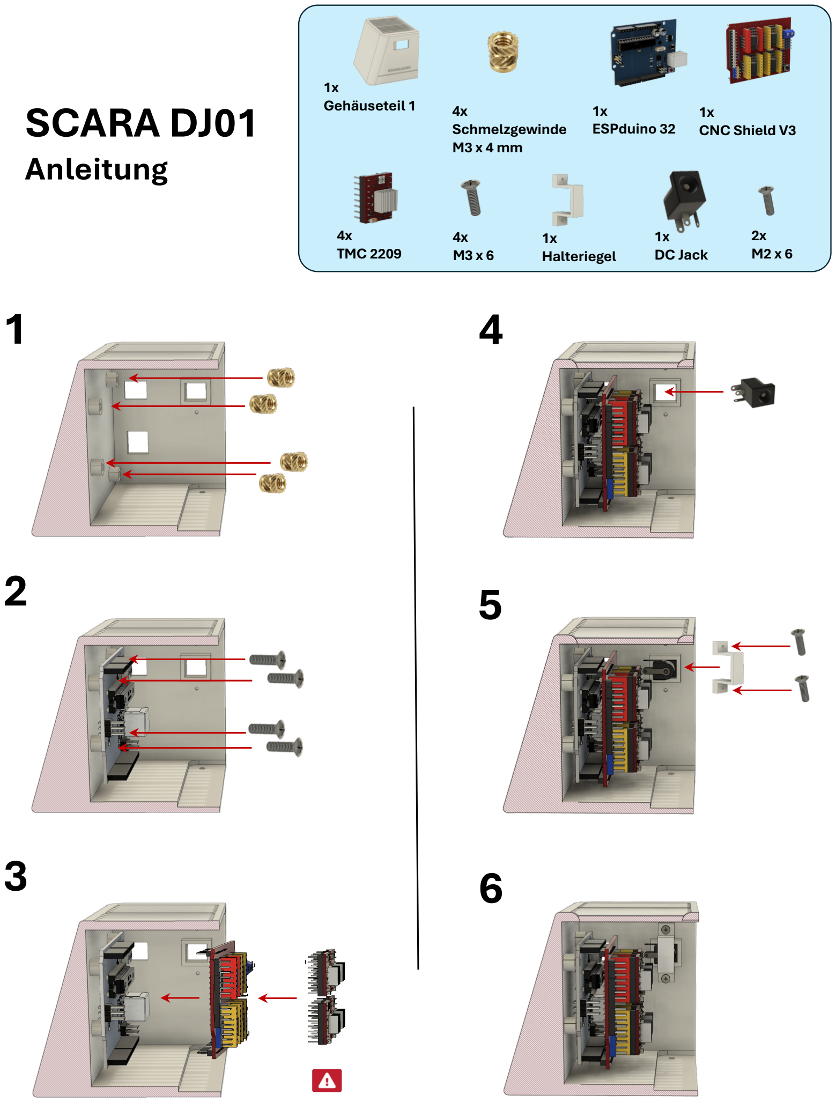
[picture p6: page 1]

1x
Gehäuseteil 1 | 4x
| Schmelzgewinde
| M3 x 4 mm

1x
ESPduino 32

1x
CNC Shield V3

4x
TMC 2209

4x
M3 x 6

1x
Halteriegel

1x
DC Jack

2x
M2 x 6
1

2

3

4

5

6

´

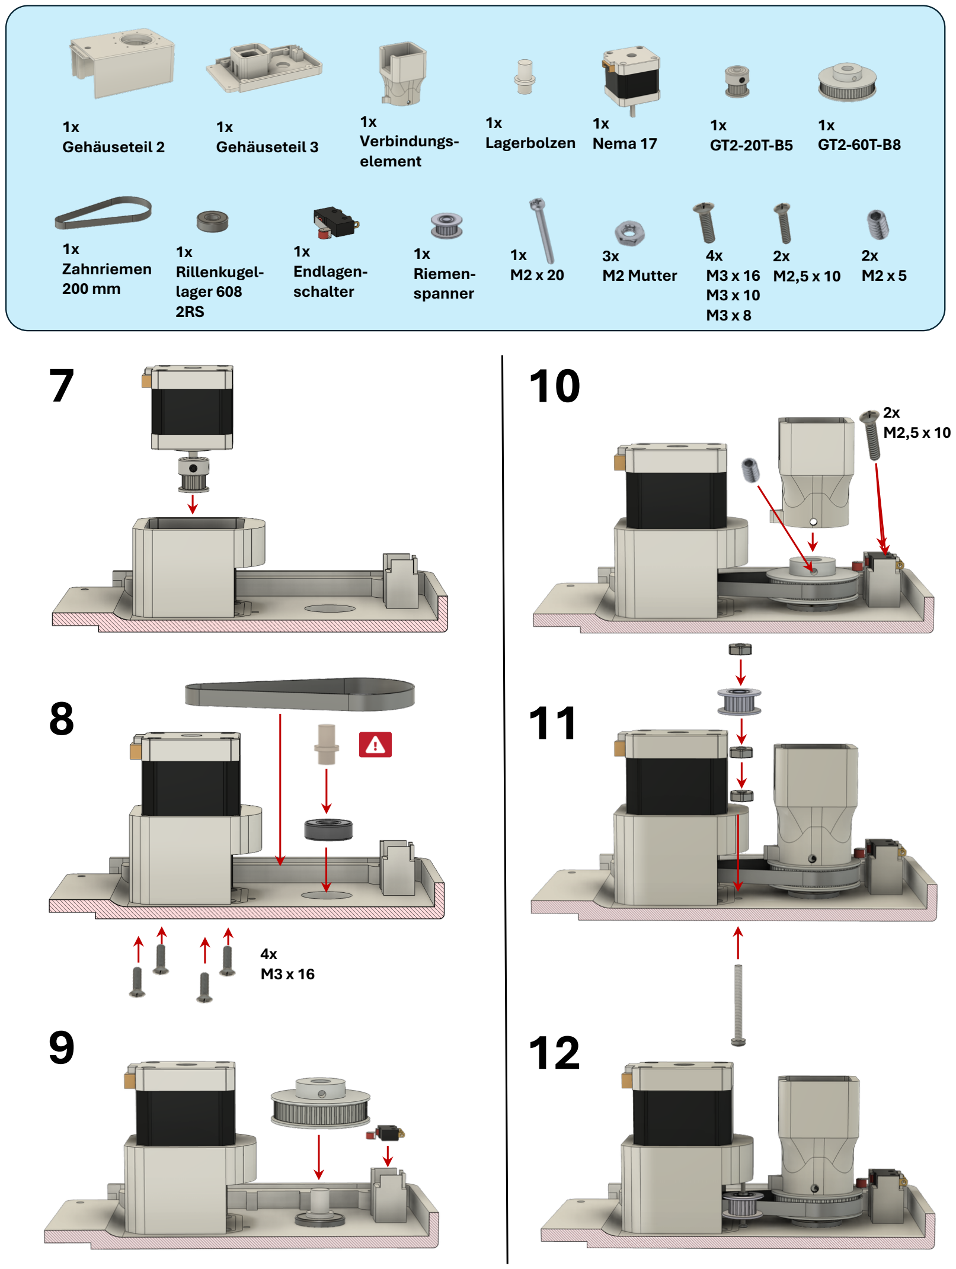
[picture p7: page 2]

1x
Gehäuseteil 2

1x
Gehäuseteil 3

1x
Verbindungselement

1x
Lagerbolzen

1x
Nema 17

1x
GT2-20T-B5

1x
GT2-60T-B8

1x
Zahnriemen
200 mm

1x
Rillenkugellager 608
2RS
7

8

9

10

1x
Endlagenschalter

1x
Riemenspanner

1x
M2 x 20

4x
M3 x 16
M3 x 10
M3 x 8

3x
M2 Mutter

2x
M2,5 x 10

2x
M2 x 5

2x
M2,5 x 10

4x
M3 x 16

11

12

13 14

1x
Linearmodul

1x
Trägerbauteil

1x
Kugellager
6808

1x
Sicherungsriegel

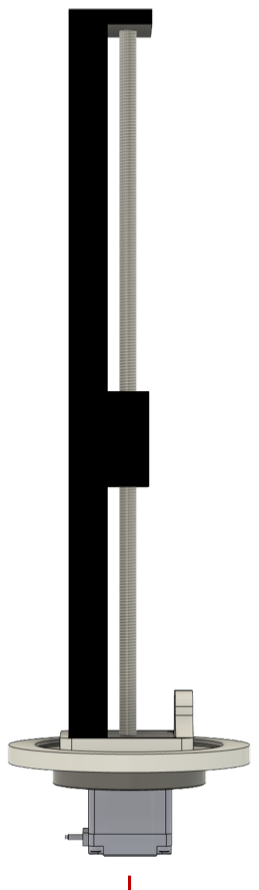
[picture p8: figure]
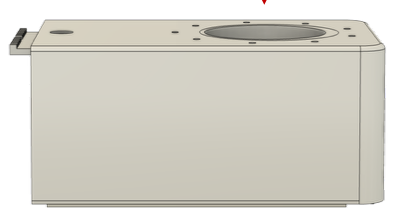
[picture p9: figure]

8x
M3 x 8

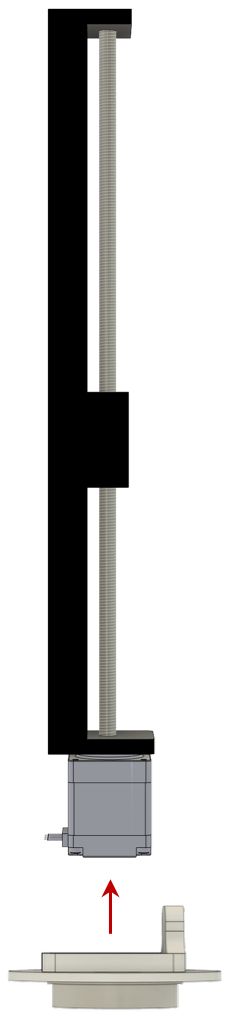
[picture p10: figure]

1x
Arm 1 Gehäuse
oben

1x
Arm 1
Gehäuse
unten

1x
Nema 11
Gehäuse

1x
Pulley 60T Bohrung
groß

1x
Nema 11

1x
GT2-20T-B5

2x
M2 x 5

3x
Riemenspanner

1x
Kugellager
6808

1x
Zahnriemen
400 mm

2x
Endlagenschalter

6x
M3 x 16

4x
M3 x 10

2x
M2 x 20

4x
M2 Mutter

8x
M2,5 x 12
15 17

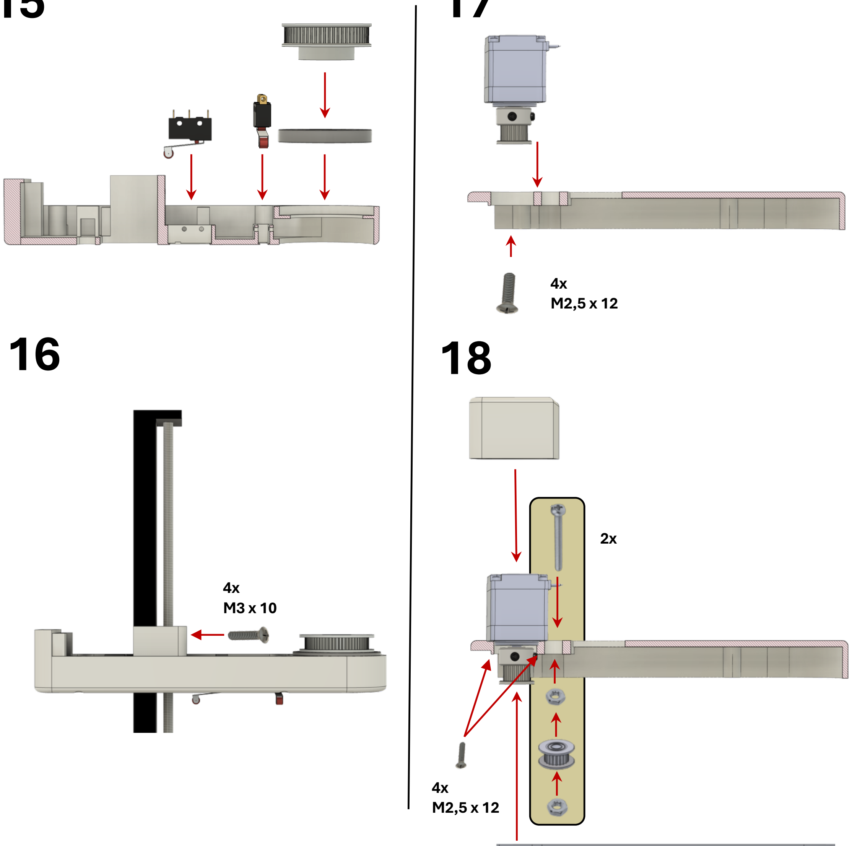
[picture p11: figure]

1x
Arm 2
Gehäuse
oben

1x
Arm 2
Gehäuse
unten

1x
Servo
MG90S

1x
Pulley 60T
Servo

1x
Endlagenschalter

1x
M2 x 20

2x
M2
Mutter

4x
M2,5 x 6
2x
M2,5 x 10

1x
Nema 11

1x
Riemenspanner

1x
Axial
Nadellager

1x
Zahnriemen
300 mm

3x
M3 x 16

2x
Zwischenlegscheibe

2x
M2 x 5

1x
GT2-20T-B5

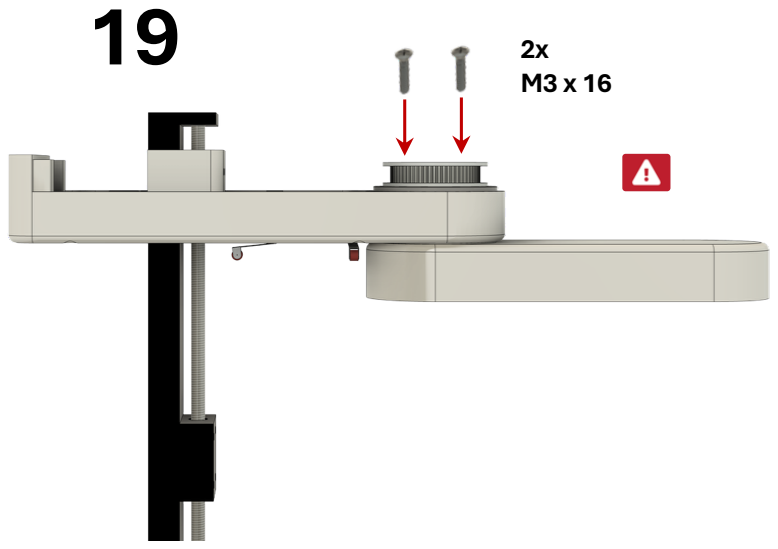
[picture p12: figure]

20

21

2x
M2,5 x 10

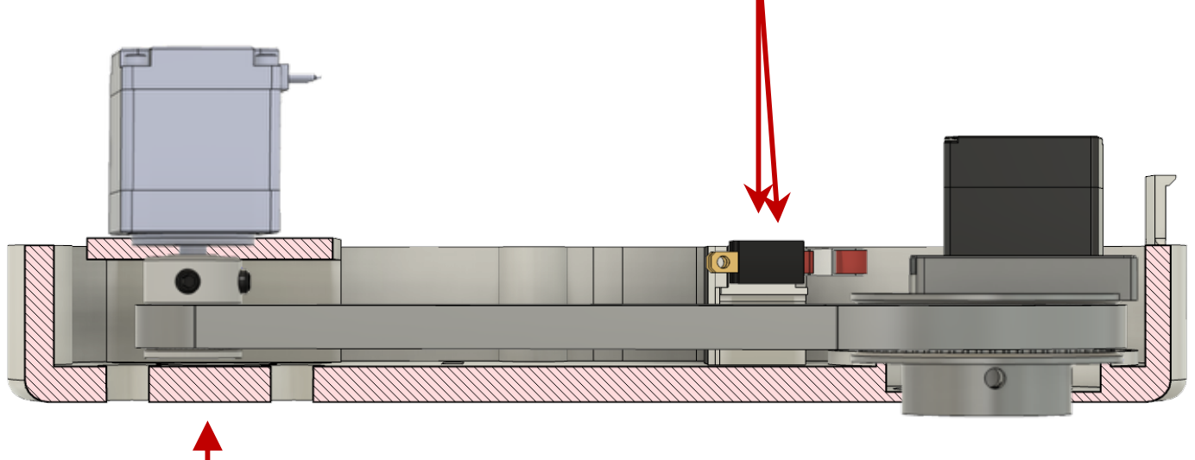
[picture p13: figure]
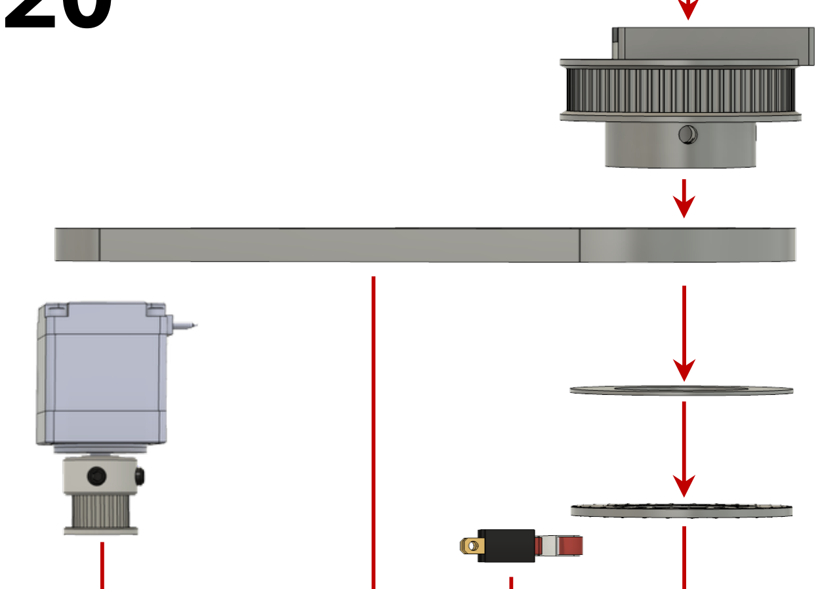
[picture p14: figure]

4x
M2,5 x 6

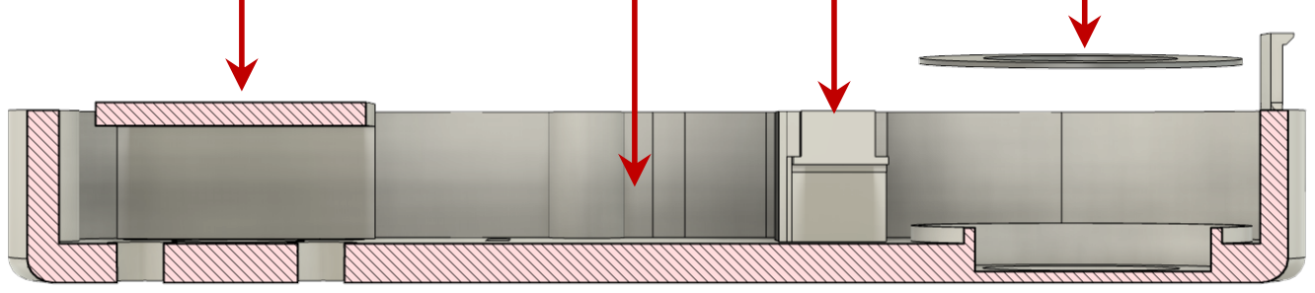
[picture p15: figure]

22
25

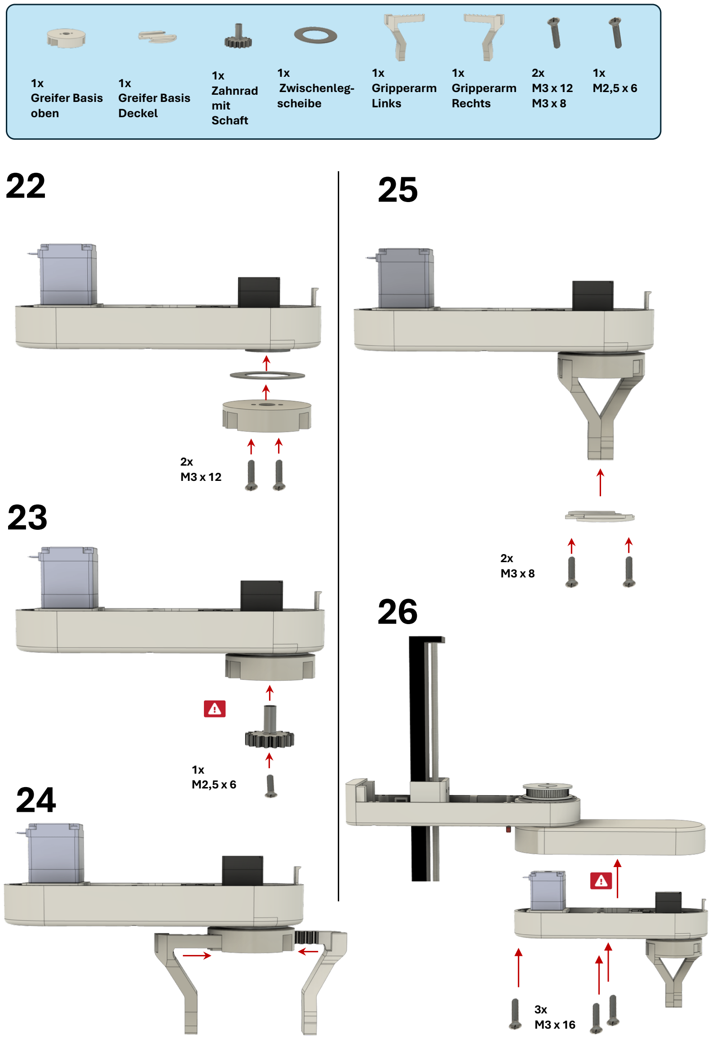
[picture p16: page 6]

1x
Greifer Basis
oben

1x
Greifer Basis
Deckel

1x
Zahnrad
mit
Schaft

1x
Zwischenlegscheibe

1x
Gripperarm
Links

1x
Gripperarm
Rechts

2x
M3 x 12
M3 x 8

1x
M2,5 x 6

23

2x
M3 x 12

1x
M2,5 x 6

2x
M3 x 8

24

26

3x
M3 x 16

27

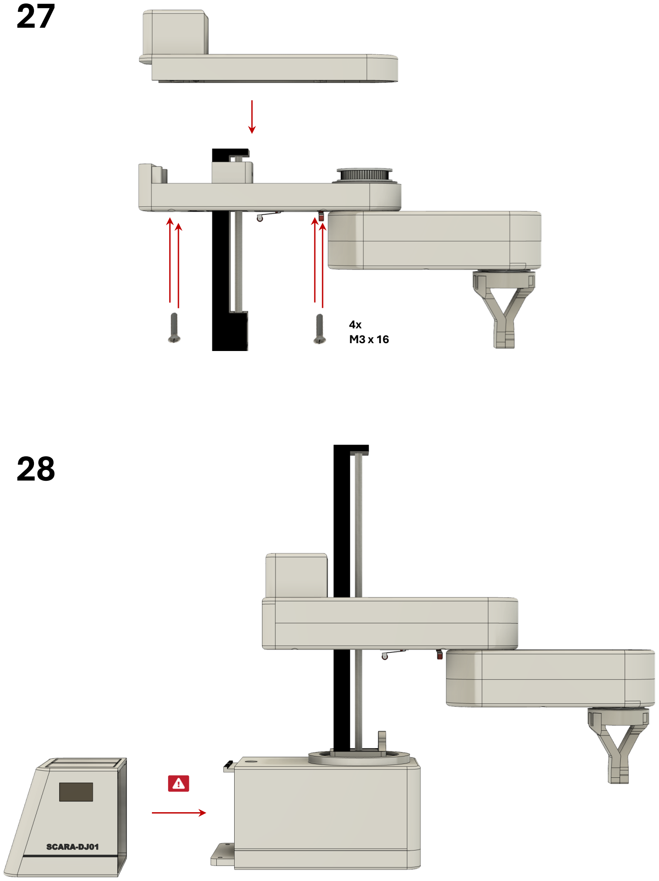
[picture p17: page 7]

4x
M3 x 16

28

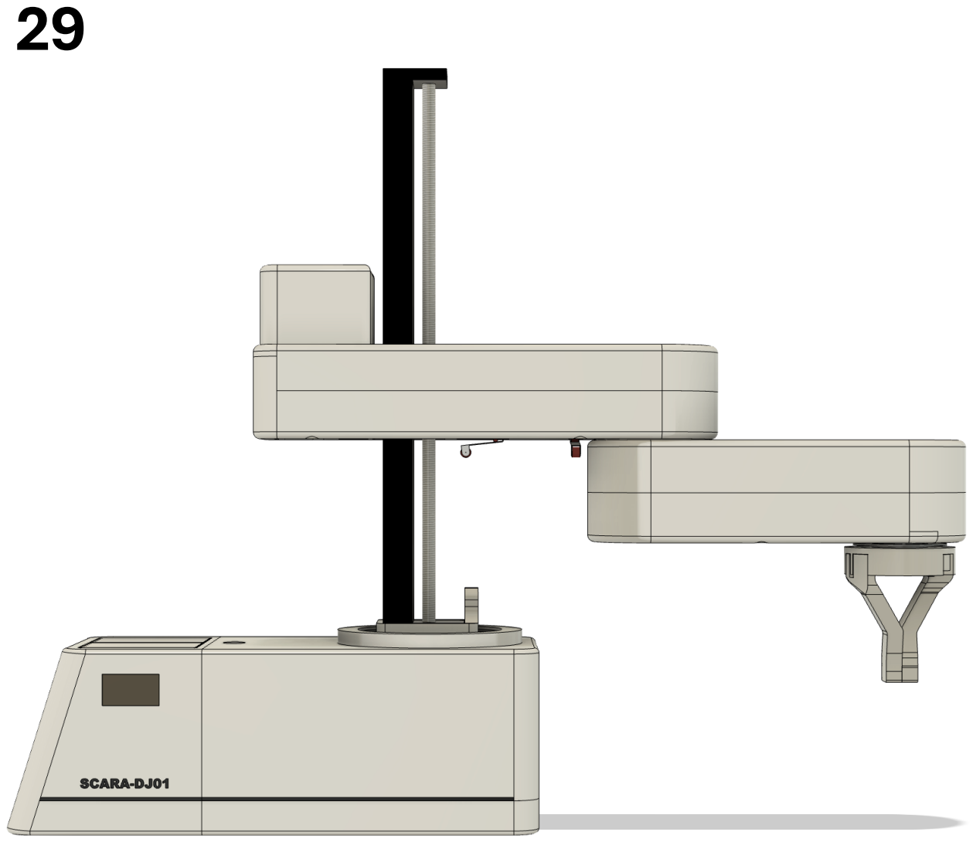
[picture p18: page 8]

29

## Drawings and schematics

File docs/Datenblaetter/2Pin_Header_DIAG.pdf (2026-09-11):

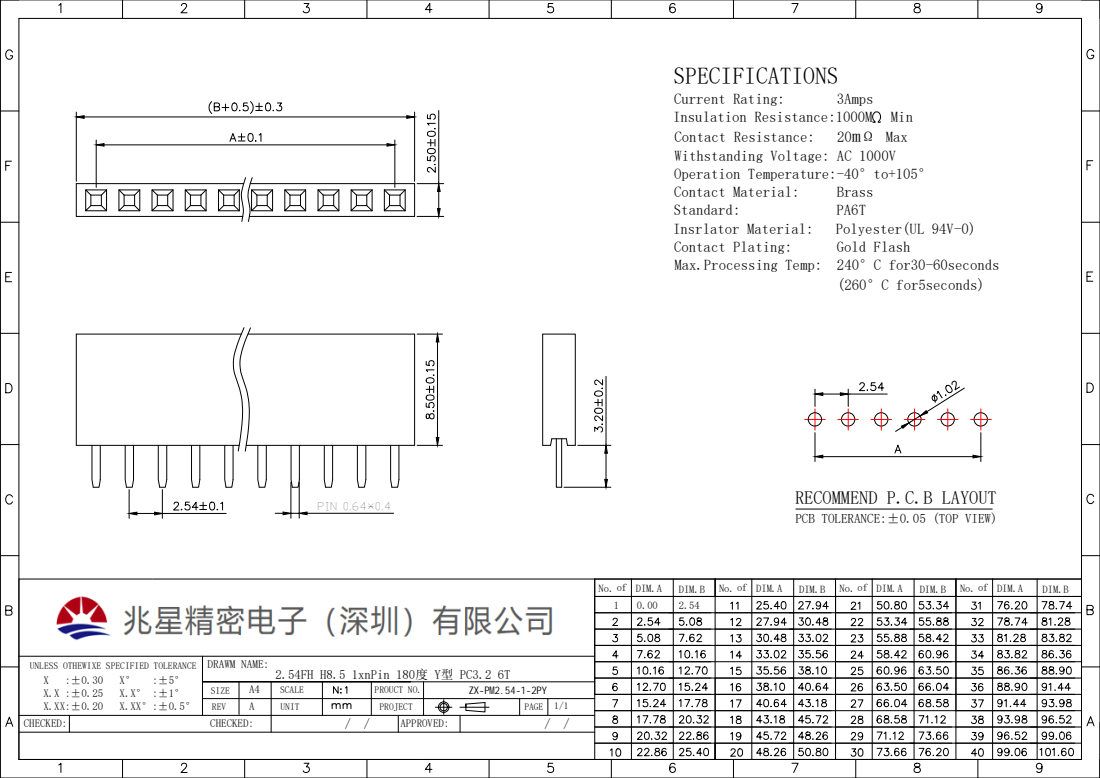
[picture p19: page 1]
2.54FH H8.5 1xnPin 180度 Y型 PC3.2 6T; SPECIFICATIONS Current Rating:; 3Amps Insulation Resistance:1000M; Min Contact Resistance:; 20mΩ Max Withstanding Voltage: AC 1000V Operation Temperature:-40°to+105° Contact Material:; Brass Standard:; PA6T Insrlator Material:; Polyester(UL 94V-0) Contact Plating:; Gold Flash Max.Processing Temp: 240°C for30-60seconds (260°C for5seconds) No. of; DIM.A; DIM.B; No. of DIM.A; DIM.B PCB TOLERANCE:±0.05 (TOP VIEW) RECOMMEND P.C.B LAYOUT No. of DIM.A; DIM.B 1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

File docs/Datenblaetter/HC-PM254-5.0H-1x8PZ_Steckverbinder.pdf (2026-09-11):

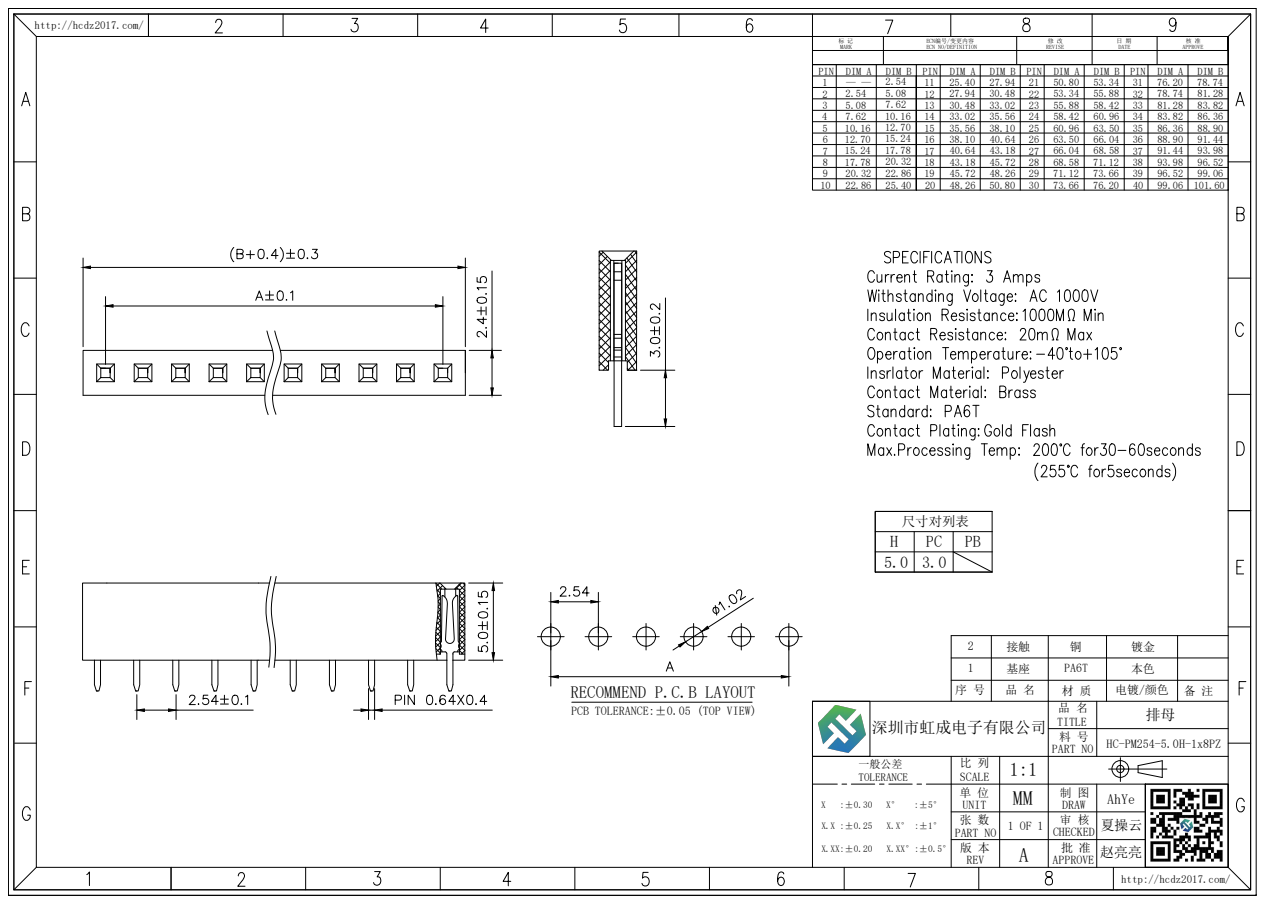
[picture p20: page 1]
比 列 SCALE REV 版 本; DRAW 制 图 CHECKED 审 核 APPROVE 批 准 1:1 1 OF 1; 夏操云 AhYe http://hcdz2017.com/; http://hcdz2017.com/ UNIT 单 位; MM 深圳市虹成电子有限公司; 张 数 PART NO 一般公差 TOLERANCE; DATE 日 期 REVISE 修 改 ECN NO/DEFINITION ECN编号/变更内容 MARK 标 记; APPROVE 核 准 X; 镀金 HC-PM254-5.0H-1x8PZ PCB TOLERANCE:±0.05 (TOP VIEW); 排母 RECOMMEND P.C.B LAYOUT; PIN12345678910; PIN; 40 222324252627282921 DIM A; DIM B; DIM A; DIM B — — 2.54 5.08 7.62 10.16 12.70 15.24 17.78 20.32 22.86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

品 名 TITLE PART NO 料 号

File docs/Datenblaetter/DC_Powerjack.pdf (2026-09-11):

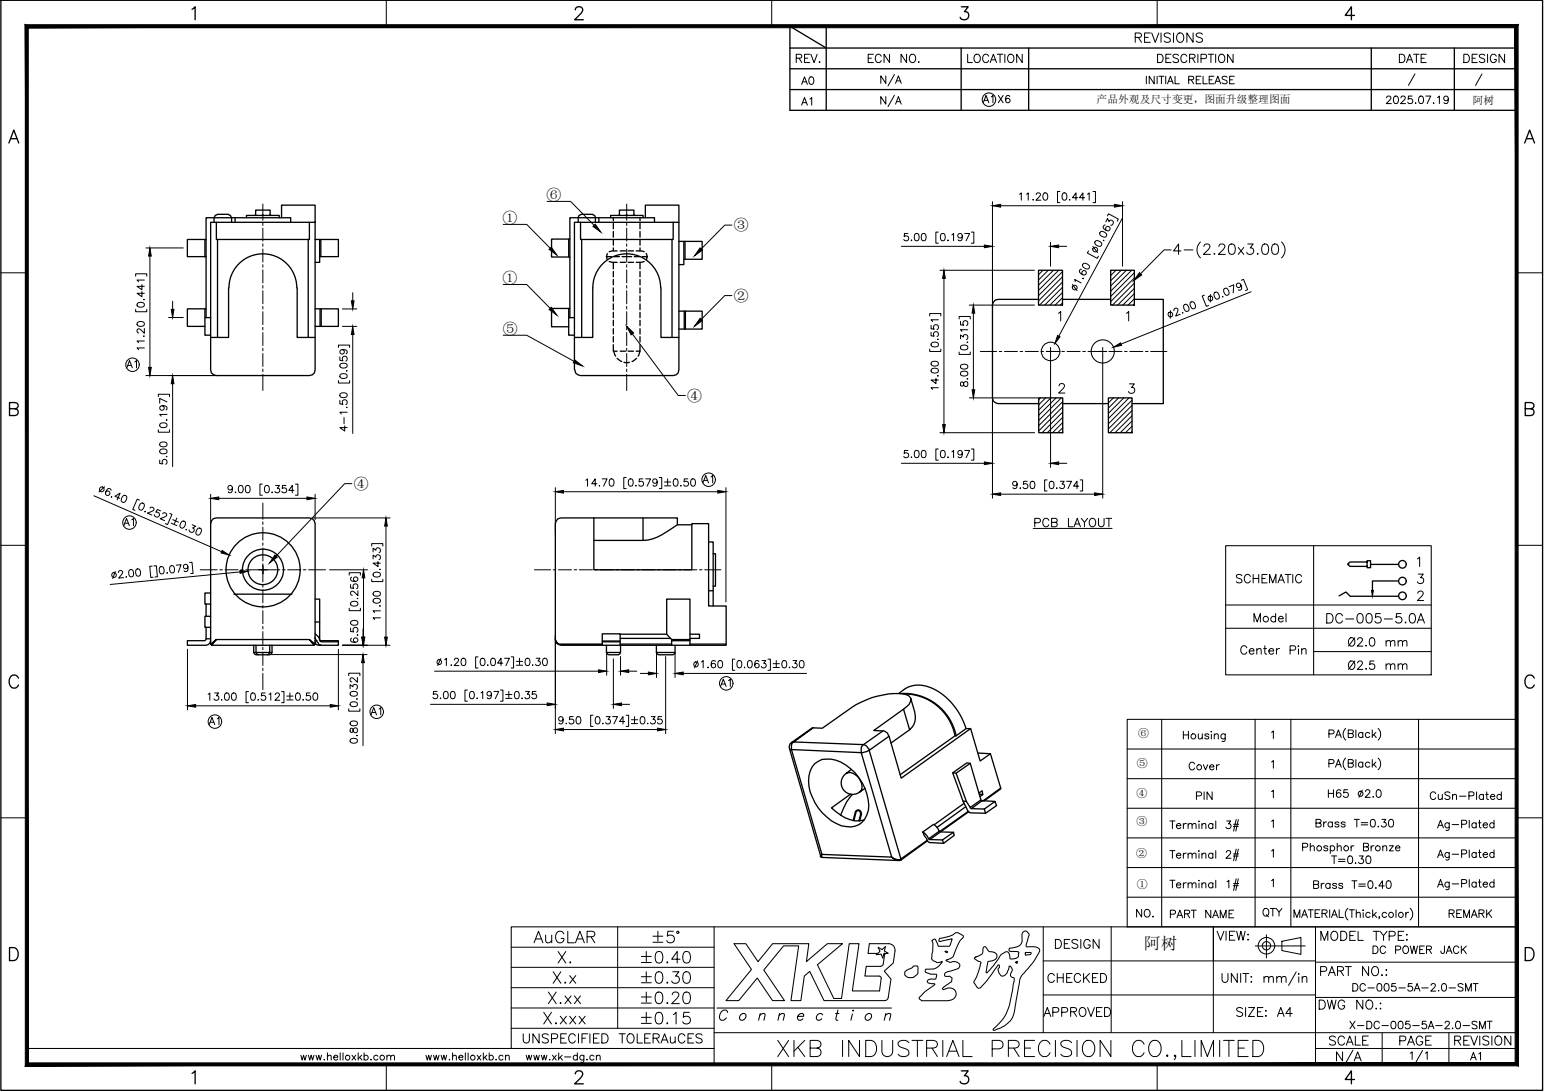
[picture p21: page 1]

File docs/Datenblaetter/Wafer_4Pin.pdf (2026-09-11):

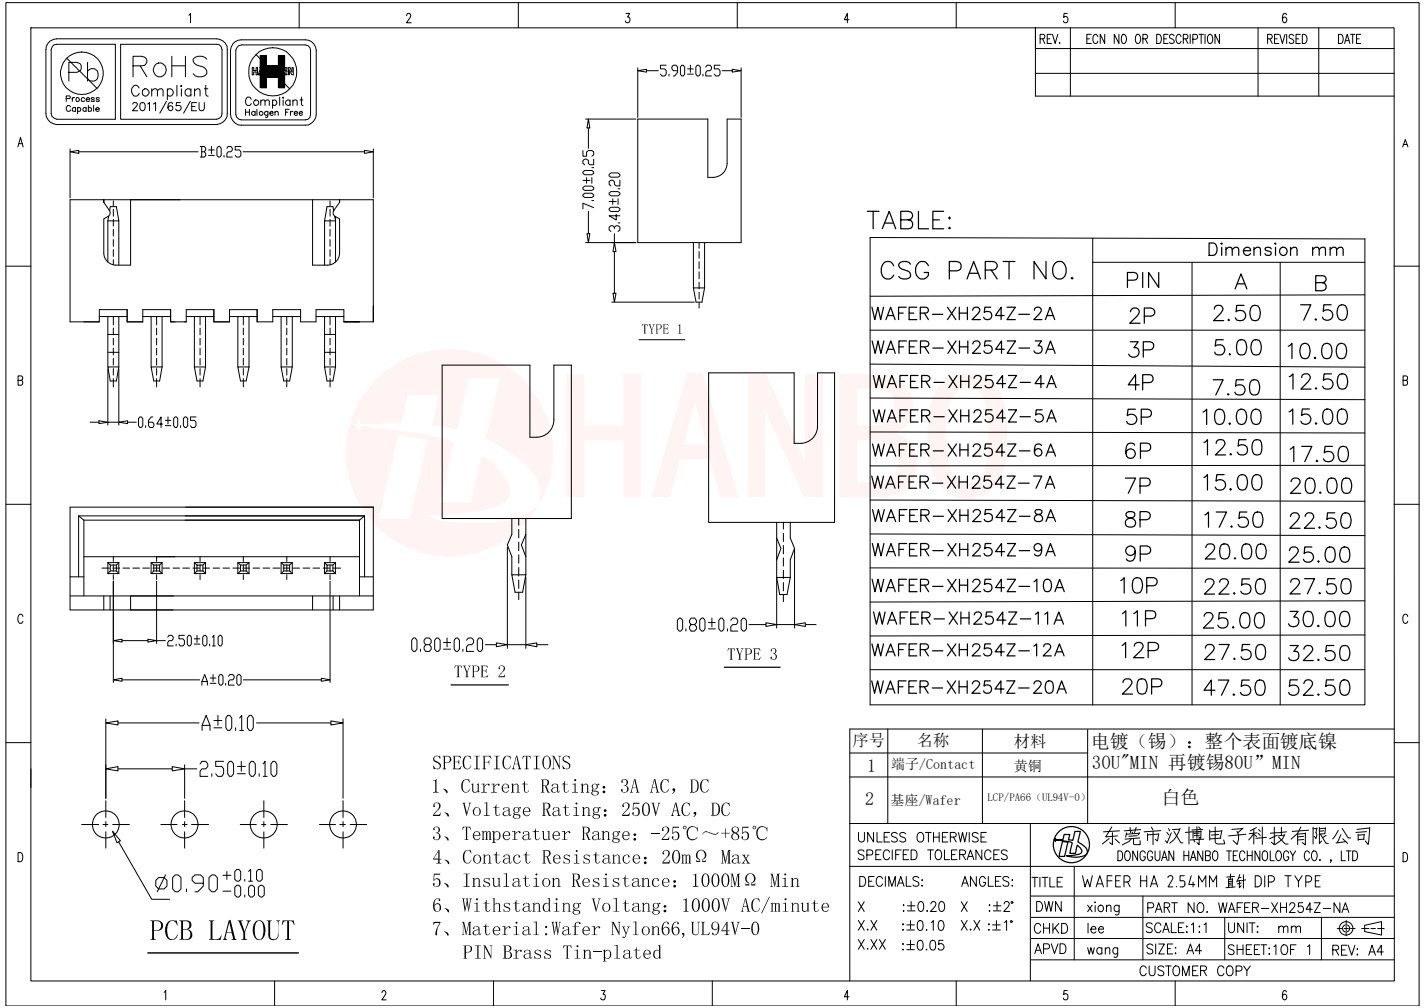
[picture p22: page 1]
电镀（锡）：整个表面镀底镍; 基座/Wafer; 端子/Contact; 30U"MIN 再镀锡80U”MIN; LCP/PA66（UL94V-0）

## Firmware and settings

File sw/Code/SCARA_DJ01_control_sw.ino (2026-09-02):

/*
  Studienprojekt I - Entwicklung und Inbetriebnahme eines SCARA-Roboters 
  Jakob Cap, David Kowalczyk 

  SCARA_DJ01 - Steuerungssofware
  Hardware: ESPduino32 + CNC Shield V3 + TMC2209 V1.3 + mechanische Endschalter + NEMA 17 und 11 Schrittmotoren + MG90S Servo

  FastAccelStepper Library: https://github.com/gin66/FastAccelStepper
  Orientiert an: https://howtomechatronics.com/projects/scara-robot-how-to-build-your-own-arduino-based-robot/
*/
#include <FastAccelStepper.h>
#include <ESP32Servo.h>
#include <BluetoothSerial.h>
#include <math.h>

//Definition des Endschalter-Pins
#define LIM1    13   //Endschalter Arm1-XY-Drehung (Motor 1)
#define LIM2    23   //Endschalter Z-Achse (Motor 2)
#define LIM3     5   //Endschalter Arm2 XY-Drehung (Motor 3)
#define LIM4    34   //Endschalter Greifer-Rotation (Motor 4)

//Definition der Motor-/Treiberpins 
#define Motor1_STEP 26
#define Motor1_DIR 16   //Motor 1 Basis (Rotation Amr1)
#define Motor2_STEP 17  
#define Motor2_DIR 14   //Motor 2 Z-Achse (Translation Z)
#define Motor3_STEP 25  
#define Motor3_DIR 27   //Motor 3 Arm1 (Rotation Arm2)
#define Motor4_STEP 19  
#define Motor4_DIR 18   //Motor4 Arm2 (Rotation Greifer)
#define EN_PIN  12  //Enable-Pin für alle Schrittmotortreiber (LOW-Aktiv)
#define SRV_PIN  2  //PWM-Pin für Greifer-Servo

//Kinematische Konstanten
#define L1     100.0  //Länge des erste Roboterarms in mm
#define L2     110.0  //Länge des zweiten Roboterarms in mm
#define SPD    13.3333  //Schritte pro Grad für alle rotatorischen Achsen (Gleichung und Berechnung s. Studienprojekt)
#define SPM   266.6667   //Schritte pro mm für die translatorische Achse (Gleichung und Berechnung s. Studienprojekt)
#define Z0     85.0 //Referenzhöhe des TCPs nach dem Homing in mm über dem Boden
#define WMAX  155.0 //maximaler Basiswinkel ±° (konstruktiv bedingt)

// Homing-Offsets (Schritte vom Endschalter bis zut absoluten Nullposition)
#define OFF1  -2382
#define OFF2  21750
#define OFF3   1715
#define OFF4    -82

// Demo-Sequenz (Pick-and-Place Ablauf) 
const float DEMO[][55] = {
  {  0, 210,  85, 100},
  {  0, 210,  15, 100},
  {  0, 210,  15, 100},
  {  0, 210,  15, 100},
  {  0, 210,  45, 100},
  {  210, 0,  45, 100},
  {  210, 0,  15, 100},
  {  210, 0,  15, 100},
  {  210, 0,  15, 100},
  {  100, 160,  15, 100},
  {  100, 160,  15, 100},
  {  100, 160,  15, 100},
  {  100, 160,  45, 100},
  {  -120, 120,  45, 100},
  {  -120, 120,  15, 100},
  {  -120, 120,  15, 100},
  {  -120, 120,  15, 100},
  {  -120, 120,  45, 100},
  {  0, 210,  85, 100}, 
  {  100, 160,  85, 100}, 
  {  100, 160,  4,  39},  
  {  100, 160,  45,  39},  
  {  0, 210,  45, 39},  
  {  0, 210,  10, 100},
  {  0, 210,  45, 100},  
  {  -120, 120,  45, 100}, 
  {  -120, 120,  4, 39},
  {  -120, 120,  45, 39}, 
  {  0, 210,  45, 39},  
  {  0, 210,  20, 100},
  {  0, 210,  45, 100},
  {  210, 0,  45, 100}, 
  {  210, 0,  4, 39},
  {  210, 0,  45, 39},
  {  0, 210,  45, 39},  
  {  0, 210,  30, 100},
  {  0, 210,  45, 100},
  {  0, 210,  29, 39},
  {  0, 210,  45, 39},
  {  100, 160,  45, 39}, 
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
};
const int DEMO_N = 55; 

//Objekt-Instanzierung
BluetoothSerial BT;
FastAccelStepperEngine eng = FastAccelStepperEngine();
FastAccelStepper *Motor1, *Motor2, *Motor3, *Motor4;
Servo servoGripper;

//Speicherstruct für eingegeben Sequenzen über Bluetooth oder serielle Schnittstelle
struct Punkt
{ 
  float x; 
  float y; 
  float z; 
  int greiferWinkel; 
};
Punkt sequenz[50];  //Array zum vorporgrammieren, maximal 50 programmierbare Schritte um Stack Overflow zu verhindern
int sequenzAnzahl = 0; //Aktuelle Anzahl gespeicherter Schritte

//Globale Variablen
uint32_t spd = 12500, acc = 7500; //Standard Betriebsgeschwindigkeit und -beschleunigung in Hz (Rechnung s. Studienprojekt)
bool estop = false; //Not-Aus Flag (Deaktiviern des EN Pins - damit stoppen aller Motoren)
bool silent = false;  //Schaltet serielle Textausgaben silent
bool loopStop = false;  //Flag zum Abbrechen von Schleifen

//Homing ISR-Flags (valoatile, da Änderung des Interrupt stattfindet)
volatile bool h1, h2, h3, h4;
//Interrupt Service Routinen werden ausgeführt sobald Endschalter auslöst
void IRAM_ATTR isr1() { h1 = true; }  //Endschalter 1 ausgelöst
void IRAM_ATTR isr2() { h2 = true; }  //"-" 2 "-"
void IRAM_ATTR isr3() { h3 = true; }  //"-" 3 "-"
void IRAM_ATTR isr4() { h4 = true; }  //"-" 4 "-"

//Ausgabefunktion sendet Text an seriellen Monitor
void out(String s) 
{
  Serial.println(s);
  if (BT.connected()) BT.println(s);
}
//Setzt Geschwindigkeit und Beschleunigung für alle 4 Motoren
void setSpeeds() 
{
  Motor1->setSpeedInHz(spd); Motor1->setAcceleration(acc);
  Motor2->setSpeedInHz(spd*1.6); Motor2->setAcceleration(acc*1.6); //Die Z-Achse muss schneller Beschleunigung aufgrund 6mm pitch
  Motor3->setSpeedInHz(spd); Motor3->setAcceleration(acc);
  Motor4->setSpeedInHz(spd); Motor4->setAcceleration(acc);
}
//Sofortiger Stop aller Motoren auf der aktuellen Position
void stopAll() {
  Motor1->forceStopAndNewPosition(Motor1->getCurrentPosition());
  Motor2->forceStopAndNewPosition(Motor2->getCurrentPosition());
  Motor3->forceStopAndNewPosition(Motor3->getCurrentPosition());
  Motor4->forceStopAndNewPosition(Motor4->getCurrentPosition());
}
//Blockiert bis Motoren Zielposition erreicht haben und prüft auf stop-Befehl
void waitAll() 
{
  while (Motor1->isRunning() || Motor2->isRunning() || Motor3->isRunning() || Motor4->isRunning()) {
    String cmd = "";
    if (Serial.available()) cmd = Serial.readStringUntil('\n');
    if (BT.available())     cmd = BT.readStringUntil('\n');
    cmd.trim();
    if (cmd == "stop") {
      stopAll();
      digitalWrite(EN_PIN, HIGH); //Motortreiber deaktivieren
      estop = true;
      return;
    }
  }
}
//Homing-Funktion (Fährt einzelne Achse langsam gegen Endschalter und setzt Offset)
void homeAxis(FastAccelStepper *m, volatile bool &flag, bool fwd, uint32_t searchSpd, long offset) 
{
  flag = false;
  m->setSpeedInHz(searchSpd); 
  m->setAcceleration(50000);  //Hohe Beschleunigung für schnellen Stop

  if (fwd) m->runForward(); 
  else m->runBackward();
  while (!flag) {} //Warten auf ISR-Trigger Flag auf true
  
  m->forceStopAndNewPosition(offset); 
  delay(50);
}
//Referenzfahrten für alle 4 Motoren
void homing() {
  stopAll(); delay(200); setSpeeds(); out("homing");

  //1. Z-Achse (Motor 2)
  homeAxis(Motor2, h2, true, 1500, OFF2);  
  Motor2->setSpeedInHz(spd*1.6); Motor2->setAcceleration(acc*1.6);
  Motor2->moveTo(0); while (Motor2->isRunning()) {}
  //2. Basis XY (Motor 1)
  homeAxis(Motor1, h1, false, 600, OFF1);  
  Motor1->setSpeedInHz(spd); Motor1->setAcceleration(acc);
  Motor1->moveTo(0); while (Motor1->isRunning()) {}
  //3. Arm1 XY (Motor 3)
  homeAxis(Motor3, h3, true, 600, OFF3);  
  Motor3->setSpeedInHz(spd); Motor3->setAcceleration(acc);
  Motor3->moveTo(0); while (Motor3->isRunning()) {}
  //4. Greifer (Motor 4)
  homeAxis(Motor4, h4, false, 600, OFF4);  
  Motor4->setSpeedInHz(spd); Motor4->setAcceleration(acc);
  Motor4->moveTo(0); while (Motor4->isRunning()) {}

  setSpeeds(); out("homing ok");
}

//Vorwärts Kinematik = Motorposition => kartesische Koordinaten
void fk()
{
  //Schritte zuerst in Winkel umrechnen
  float theta1 = Motor1->getCurrentPosition() / SPD + 90.0; //+90° Offset für mathematische Konvention
  float theta2 = Motor3->getCurrentPosition() / SPD;
  float zm     = Motor2->getCurrentPosition() / SPM;
  
  float theta1r = theta1 * 0.017453;  //Umrechnung in Bogenmaß
  float theta2r = theta2 * 0.017453;
  //Trigonometrische Berechnungen TCP
  float x = L1 * cos(theta1r) + L2 * cos(theta1r + theta2r);
  float y = L1 * sin(theta1r) + L2 * sin(theta1r + theta2r);
  float z = Z0 - zm; //Z-Höhe invers zur Spindel-Fahrt berechnet
  
  out("FK:"+ String(x, 1)+ "," + String(y, 1)+ "," + String(z, 1));
}

//Inverse Kinematik (IK)
bool ik(float tx, float ty, float tz) 
{
  //1. Erreichbarkeitsprüfung
  float dist = sqrt(tx*tx + ty*ty);
  if (dist > 210.0 || dist < 120.0) 
  {
    if (!silent) out("Punkt nicht im Arbeitsraum"); //Ziel außerhalb des physikalischen Radius
    return false; 
  }
  //2. Winkelprüfung
  float ang = atan2(tx, ty) * 57.2958;
  if (ang < -WMAX || ang > WMAX) 
  { 
    if (!silent) out("Winkel Error"); 
    return false; 
  }
  //Koordinaten-Transformation (X+=rechts, Y+=vorne) in mathematisch
  float mx = ty; 
  float my = -tx;
  //Berechnung des Cosinussatzes für das Ellenbogengelenk
  float c2 = (mx * mx + my * my - L1 * L1 - L2 * L2) / (2.0 * L1 * L2);
  if (c2 < -1.0) c2 = -1.0; //Kosinus wird auf Bereich -1;1 eingegrenzt
  if (c2 >  1.0) c2 =  1.0;
  float s2p = sqrt(1.0 - c2 * c2); //Positive Wurzel = "Ellenbogen oben" 
  //Berechnung der zwei mathematisch möglichen Lösungen "Ellenbogen oben","Ellenbogen unten"
  float theta1a = (atan2(my,mx) - atan2( L2*s2p, L1+L2*c2)) * 57.2958;
  float theta2a =  atan2( s2p, c2) * 57.2958;

  float theta1b = (atan2(my,mx) - atan2(-L2*s2p, L1+L2*c2)) * 57.2958;
  float theta2b =  atan2(-s2p, c2) * 57.2958;
  //Entscheidung für optimale Lösung mit geringster Basisdrehung
  float theta1 = 0;
  float theta2 = 0;
  bool loesungA_ok = (fabs(theta1a) <= WMAX);
  bool loesungB_ok = (fabs(theta1b) <= WMAX);

  if (loesungA_ok && loesungB_ok)
  {
    //Lösung mit dem kleineren Betrag
    if (fabs(theta1a) <= fabs(theta1b))
    {
      theta1 = theta1a;
      theta2 = theta2a;
    } else 
    {
      theta1 = theta1b;
      theta2 = theta2b;
    }
  } else if (loesungA_ok)
  {
    theta1 = theta1a;
    theta2 = theta2a;
  } else if (loesungB_ok)
  {
    theta1 = theta1b;
    theta2 = theta2b;
  } else {
    if (!silent) out("ik nicht möglich");
    return false;
  }
  //Greifer-Kompensation - Hält den Greifer immer parallel zur X-Achse
  float phi = +(theta1 + theta2);
  while (phi >  180.0) phi -= 360.0;
  while (phi < -180.0) phi += 360.0;
  //Umrechnung der berechneten Winkel/Höhen in Schritte für die Motoren
  long p1 = lround(theta1 * SPD);
  long p2 = lround((Z0 - tz) * SPM);
  long p3 = lround(theta2 * SPD);
  long p4 = lround(phi    * SPD);
  //Softwarebeggrenzung der Motorschritte um mechanische Kollisionen zu vermeiden
  if (p1 < -2200 || p1 > 2200)   { if (!silent) out("Limit Motor1"); return false; }
  if (p2 < -22667|| p2 > 22667)  { if (!silent) out("Limit Motor2"); return false; }
  if (p3 < -1720 || p3 > 1720)   { if (!silent) out("Limit Motor3"); return false; }
  //Motoren bewegen zu Zielschritten
  Motor1->moveTo(p1); 
  Motor2->moveTo(p2); 
  Motor3->moveTo(p3);
  if (p4 >= -2400 && p4 <= 2400)
  {
    Motor4->moveTo(p4);
  }
  waitAll();
  if (!estop && !silent) 
  {
    out("Ok");
  }
  return !estop;
}

//Funktion zum Ausführen der Sequenz
void runSeq() {
  if (sequenzAnzahl == 0) { out("Sequenz leer"); return; }
  silent = true; //Serielle Ausgaben blockieren
  for (int i = 0; i < sequenzAnzahl && !estop && !loopStop; i++) 
  {
    ik(sequenz[i].x, sequenz[i].y, sequenz[i].z);
    if (sequenz[i].greiferWinkel >= 0) { 
      servoGripper.write(sequenz[i].greiferWinkel); 
      delay(500); 
    }
  }
  silent = false;
  if (!estop) out("Sequenz ok");
}
//Führt eingespeicherte Demo-Sequenz einmalig aus
void runDemo() {
  if (estop) return;
  silent = true;
  for (int i = 0; i < DEMO_N && !estop && !loopStop; i++)
  {
    ik(DEMO[i][0], DEMO[i][1], DEMO[i][2]);
    servoGripper.write((int)DEMO[i][3]); 
    delay(500);
  }
  silent = false;
  if (!estop) out("Demo ok");
}

//Hilfsfunktion zur Überprüfung von Loop-Abbrüchen
void loopIr() {
  String inc = "";
  if (Serial.available()) inc = Serial.readStringUntil('\n');
  if (BT.available())     inc = BT.readStringUntil('\n');
  inc.trim();
  if (inc == "stop")
  { 
    stopAll(); 
    digitalWrite(EN_PIN, HIGH); 
    estop = true; 
    out("Stop"); 
  }
  if (inc == "ls") 
  { 
    loopStop = true; 
    out("Loop Stop"); 
  }
}

//Parser (Befehlsverarbeitung)
void parse(String &c) 
{
  c.trim();
  if (c.length() == 0) return;
  //Globale Systembefehle
  if (c == "stop")   { stopAll(); digitalWrite(EN_PIN, HIGH); estop = true; loopStop = true; out("Stop"); return; }
  if (c == "enable") { estop = false; loopStop = false; digitalWrite(EN_PIN, LOW); setSpeeds(); out("Enable"); return; }
  if (estop) return; //Wet Notaus aktiv alle weiteren Befehle blockieren

  //Standard-Einzelbefehle
  if (c == "ls")    { loopStop = true; out("Loop Stop"); return; }
  if (c == "h")     { homing();  return; }
  if (c == "fk")    { fk();      return; }
  if (c == "run")   { runSeq(); return; }
  if (c == "demo")  { loopStop = false; runDemo(); return; }
  if (c == "clear") { sequenzAnzahl = 0; out("Clear"); return; }
  if (c == "del")   { if (sequenzAnzahl > 0) sequenzAnzahl--; out(String(sequenzAnzahl)); return; }

  //Sequenz loopen
  if (c == "loop") 
  {
    loopStop = false; out("Loop");
    while (!estop && !loopStop)
    {
      runSeq();
      loopIr();
    }
    loopStop = false;
    return;
  }

  //Demo wiederholen
  if (c == "demoloop")
  {
    loopStop = false; out("Demo Loop");
    while (!estop && !loopStop)
    {
      runDemo();
      loopIr();
    }
    loopStop = false;
    return;
  }
  //Ausgabe der aktuellen Sequenzdaten
  if (c == "seq") 
  {
    for (int i = 0; i < sequenzAnzahl; i++) 
    {
      out(String(i + 1) + ":" + String(sequenz[i].x, 1) + "," + String(sequenz[i].y, 1) + "," + String(sequenz[i].z, 1) + "," + sequenz[i].greiferWinkel);
    }
    return;
  }

  //Befehle für Greifer und Geschwindigkeitprofile
  if (c.startsWith("gp ")) { servoGripper.write(constrain(c.substring(3).toInt(), 0, 180)); return; }
  if (c.startsWith("sp ")) { spd = c.substring(3).toInt(); setSpeeds(); out("SP:" + String(spd)); return; }
  if (c.startsWith("ac ")) { acc = c.substring(3).toInt(); setSpeeds(); out("AC:" + String(acc)); return; }

  //Direktfahrbefehle Achsen (Slider-Eingaben der SCARA Control App)
  if (c.startsWith("a1 ")) 
  {
    long t = lround(c.substring(3).toFloat() * SPD);
    if (t >= -2200 && t <= 2200) { Motor1->moveTo(t); while(Motor1->isRunning()){} } return;
  }
  if (c.startsWith("a2 "))
  {
    long t = lround((Z0 - c.substring(3).toFloat()) * SPM);
    if (t >= -22667 && t <= 22667) { Motor2->moveTo(t); while(Motor2->isRunning()){} } return;
  }
  if (c.startsWith("a3 ")) 
  {
    long t = lround(c.substring(3).toFloat() * SPD);
    if (t >= -1715 && t <= 1715) { Motor3->moveTo(t); while(Motor3->isRunning()){} } return;
  }
  if (c.startsWith("a4 ")) 
  {
    long t = lround(c.substring(3).toFloat() * SPD);
    if (t >= -1200 && t <= 1200) { Motor4->moveTo(t); while(Motor4->isRunning()){} } return;
  }

  //Direktbefehl Inverse Kinematik
  if (c.startsWith("ik "))
  {
    int a = c.indexOf(' ', 3);
    int b = c.indexOf(' ', a + 1);
    if (a > 0 && b > 0) {
      ik(c.substring(3, a).toFloat(), c.substring(a + 1, b).toFloat(), c.substring(b + 1).toFloat());
    }
    return;
  }

  //Punkt in Sequenzliste einfügen
  if (c.startsWith("sik")) 
  {
    if (sequenzAnzahl >= 50) { out("Sequenz voll"); return; }
    String p = c.startsWith("sikg ") ? c.substring(5) : c.substring(4);
    int a = p.indexOf(' ');
    int b = p.indexOf(' ', a + 1);
    int d = p.indexOf(' ', b + 1);
    
    if (a < 0|| b < 0) return;
    
    float x = p.substring(0, a).toFloat();
    float y = p.substring(a + 1, b).toFloat();
    float z; 
    int greiferWinkel = -1;
    
    if (d > 0) { 
      z = p.substring(b + 1, d).toFloat(); 
      greiferWinkel = constrain(p.substring(d + 1).toInt(), 0, 180); 
    } else { 
      z = p.substring(b + 1).toFloat(); 
    }
    
    sequenz[sequenzAnzahl++] = {x, y, z, greiferWinkel};
    out("S:" + String(sequenzAnzahl));
    return;
  }
}

void setup() 
{
  Serial.begin(115200);
  BT.begin("SCARA_DJ01"); //Bluetooth-Name
  //Pin-Modes festlegen
  pinMode(EN_PIN, OUTPUT); 
  digitalWrite(EN_PIN, LOW);
  pinMode(LIM1, INPUT_PULLUP);
  pinMode(LIM2, INPUT_PULLUP);
  pinMode(LIM3, INPUT_PULLUP);
  pinMode(LIM4, INPUT); 
  //FastAccelStepper engine starten und Pins zuweisen
  eng.init();
  Motor1 = eng.stepperConnectToPin(Motor1_STEP); Motor1->setDirectionPin(Motor1_DIR);
  Motor2 = eng.stepperConnectToPin(Motor2_STEP); Motor2->setDirectionPin(Motor2_DIR);
  Motor3 = eng.stepperConnectToPin(Motor3_STEP); Motor3->setDirectionPin(Motor3_DIR);
  Motor4 = eng.stepperConnectToPin(Motor4_STEP); Motor4->setDirectionPin(Motor4_DIR);
  setSpeeds();
  //Servo intialisieren mit min und max Pulsbreite
  servoGripper.attach(SRV_PIN, 600, 2500); 
  servoGripper.write(100);
  //Hardware-Interrupts an Endschalter pinnen
  attachInterrupt(digitalPinToInterrupt(LIM1), isr1, RISING);
  attachInterrupt(digitalPinToInterrupt(LIM2), isr2, RISING);
  attachInterrupt(digitalPinToInterrupt(LIM3), isr3, RISING);
  attachInterrupt(digitalPinToInterrupt(LIM4), isr4, RISING);

  out("SCARA-DJ01 Bereit!");
}

void loop() 
//durchgehendes Prüfen ob Befehle reinkommen über USB oder Bluetooth
{
  if (Serial.available()) 
  { 
    String cmd = Serial.readStringUntil('\n'); 
    parse(cmd); 
  }
  if (BT.available()) 
  { 
    String cmd = BT.readStringUntil('\n');     
    parse(cmd); 
  }
}

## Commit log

2026-09-02 Hinzufuegen der bisherigen Projektdateien
    [Mikrocontrollergehäuse.step]
2026-10-16 Komponenten-Anordnung PCB
